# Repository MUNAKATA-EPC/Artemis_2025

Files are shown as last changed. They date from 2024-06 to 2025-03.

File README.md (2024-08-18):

# Artemis_2025

宗高アルテミス 2025シーズンリポジトリです。

2025シーズンはSoccer OpenLeagueに出場します。

## リポジトリについて (引用：2024シーズンリポジトリ)
・フォルダ階層をきれいにしよう  
・パス設定は相対パス基準にしよう  
・あとは動けばなんでもよし。  

## 命名規則など (一部引用：2024シーズンリポジトリ)
・各ロボットごとにプロジェクトファイルを作成しましょう。(英字表記推奨、フォルダ名に2バイト文字は嫌じゃ！！！！)  
　ex. Project_hogehugaNode

・PlatformIO等で作成されたプロジェクトフォルダの名前は (プロジェクト名)-(開発環境) にしましょう。  
　ex. hogehoge-teensy40 hugahuga-seeeduinoxiaorp2040
 
・KiCad、Fusion360などで作成されたフォルダ、ファイルの名前は一目でわかる名前にしましょう。  
　間違ってもファイル名を"unko"とかにするなよ！！！！！(戒め)

 ## 開発環境
 |種類|使用ソフト|
 |:---:|:---|
 |機体設計|Autodesk Fusion|
 |回路設計|KiCad 7.x (only use 7.x ver.)|
 |ソフト開発|Microsoft Visual Studio Code (with PlatformIO)<br>Arduino IDE<br>OpenMV IDE|

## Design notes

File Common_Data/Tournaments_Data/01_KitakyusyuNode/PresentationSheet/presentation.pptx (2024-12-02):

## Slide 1

チーム情報

チームメンバー
松田 魁琉 　 / 　目野 優輝
石原 廉太郎 　/ 　熊抱 崚太

所属ノード
九州ブロック 福岡ノード

参加リーグ
サッカー・オープンリーグ

使用ツール

> Autodesk Fusion
ロボット全体の設計や、3Dプリンターで
印刷・CNCで加工するためのデータ作成
> KiCad 7.0
外注するための基板データの作成
> Visual Studio Code
メインマイコン・各センサー処理用の
マイコンのプログラムの作成
> MaixPy IDE
UnitV(カメラ)に書き込むプログラムの
作成、カラートラッキング用データの
調整

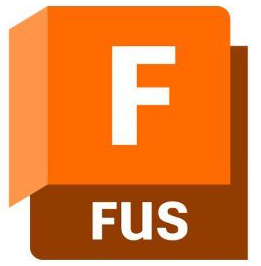
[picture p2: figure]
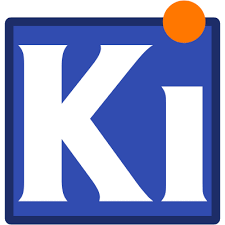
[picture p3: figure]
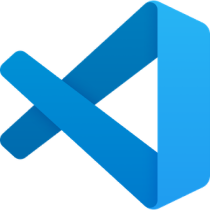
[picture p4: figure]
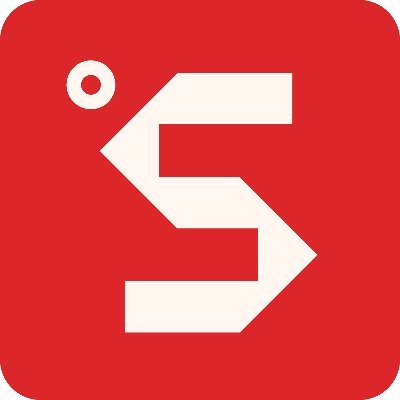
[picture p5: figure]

スポンサー

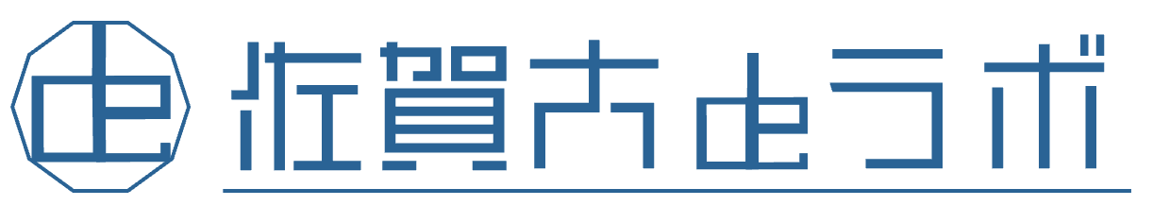
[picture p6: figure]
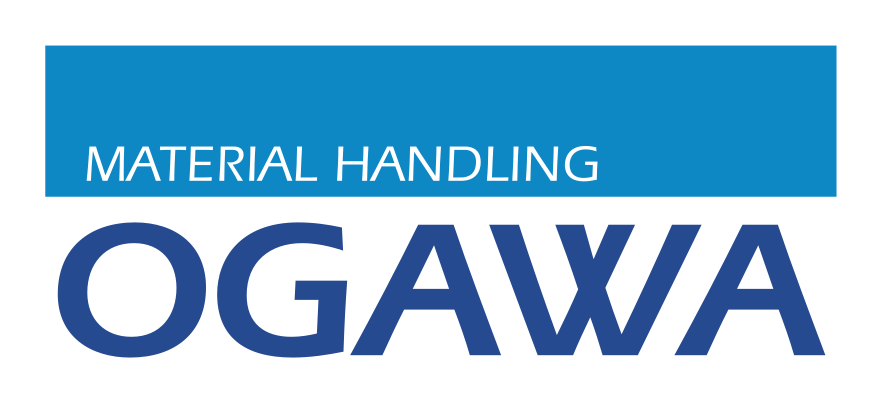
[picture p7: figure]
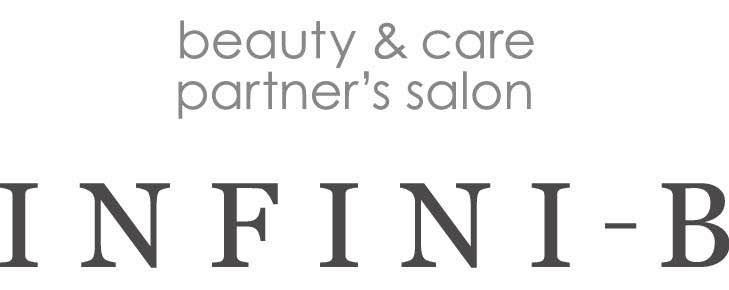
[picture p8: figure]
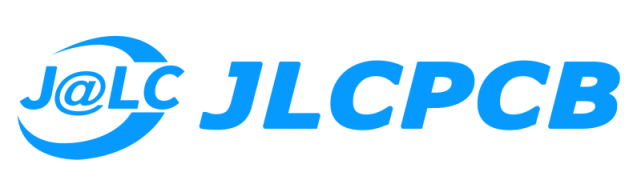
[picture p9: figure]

各種リンク

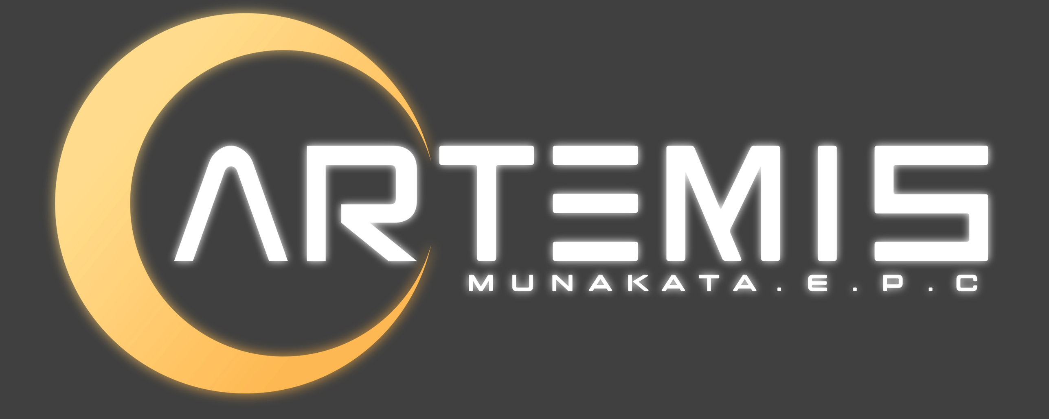
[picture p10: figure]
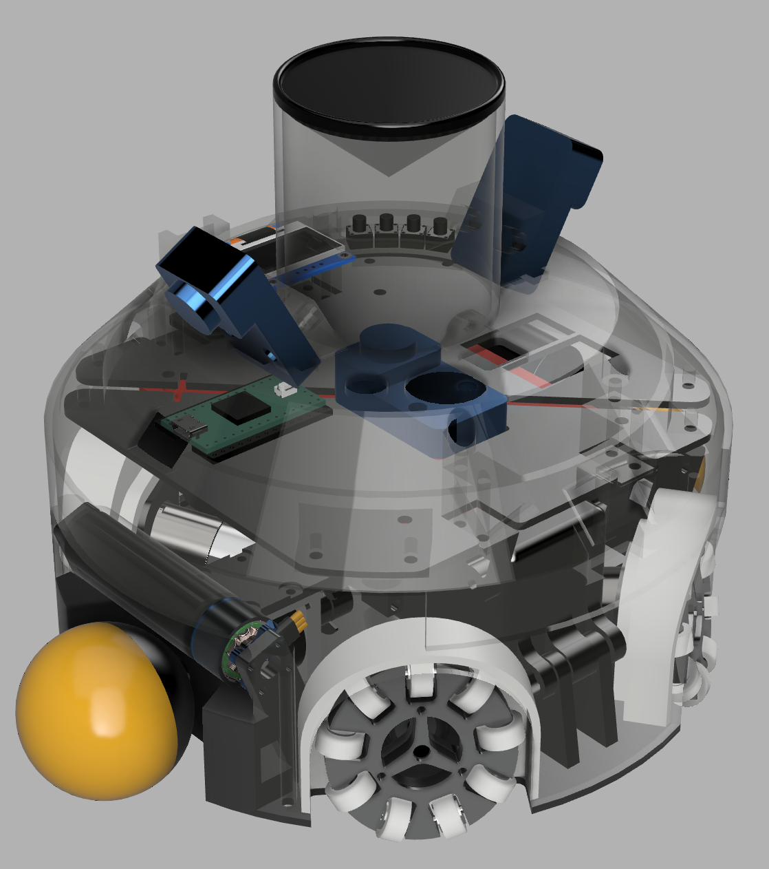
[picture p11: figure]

確実にボールを「見る」

私たちのロボットには、

電源基板 Power Supply Board
【メイン基板方向】
・5V生成
OKL-T/6-W12N-C
【ソレノイド方向】
・48V生成
(昇圧の型番)

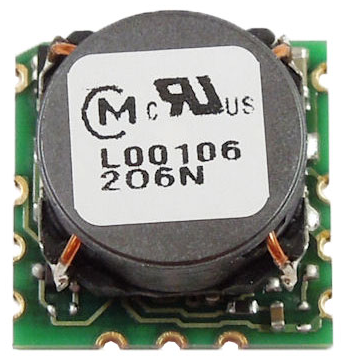
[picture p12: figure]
ムラタ表面実装DC-DCコンバーター OKL-T/6-W12N-C

【ドリブラー部分】
・ESC
??? x 2
・モーター
BLDC x 2

モーター関連
【4輪駆動部分】
・モータードライバ
DSR1202 (DAISEN製)
・モーター
IG22 1:19 x 4

Motors

バッテリー
11.1V 2200mAh

POWER

メイン基板 Main Board

メインマイコン
Teensy 4.0

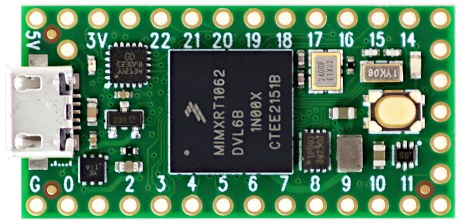
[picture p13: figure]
Teensy® 4.0

ジャイロセンサ
BNO055

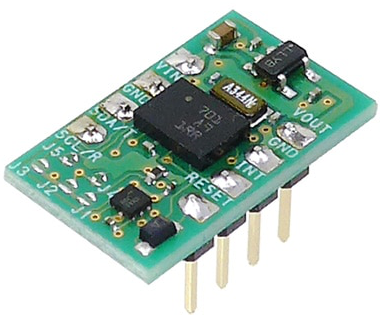
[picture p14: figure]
BNO055使用 9軸センサーフュージョンモジュールキット

UART

I²C

カメラ
UnitV
AI Camera
x 3

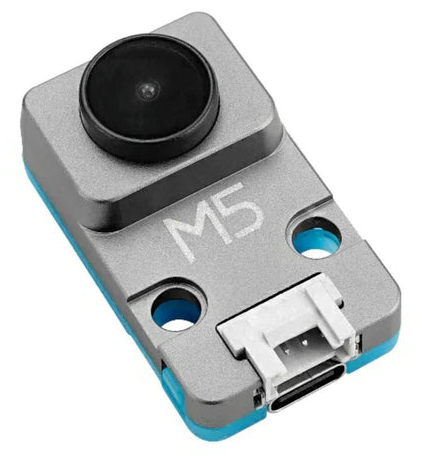
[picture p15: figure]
M5STACK-U078-V-M12

O-LEDディスプレイ
SSD1306

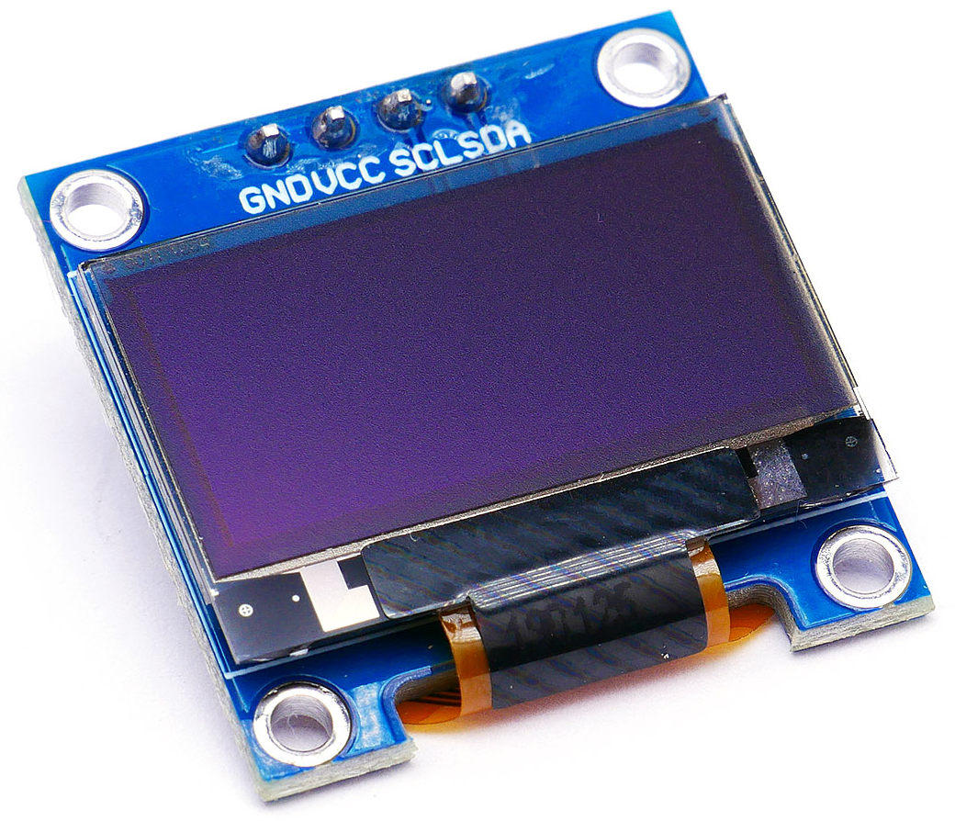
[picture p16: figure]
ESP8255でSSD1306を駆動

I²C

ラインセンサ Line Sensors

マイコン
Seeeduino Xiao x 1
(マルチプレクサを用いて
計16個分のセンサーの値を取得)
センサー
フォトトランジスタ
NJL7502L * 32
(センサーを2つずつ並列に接続)

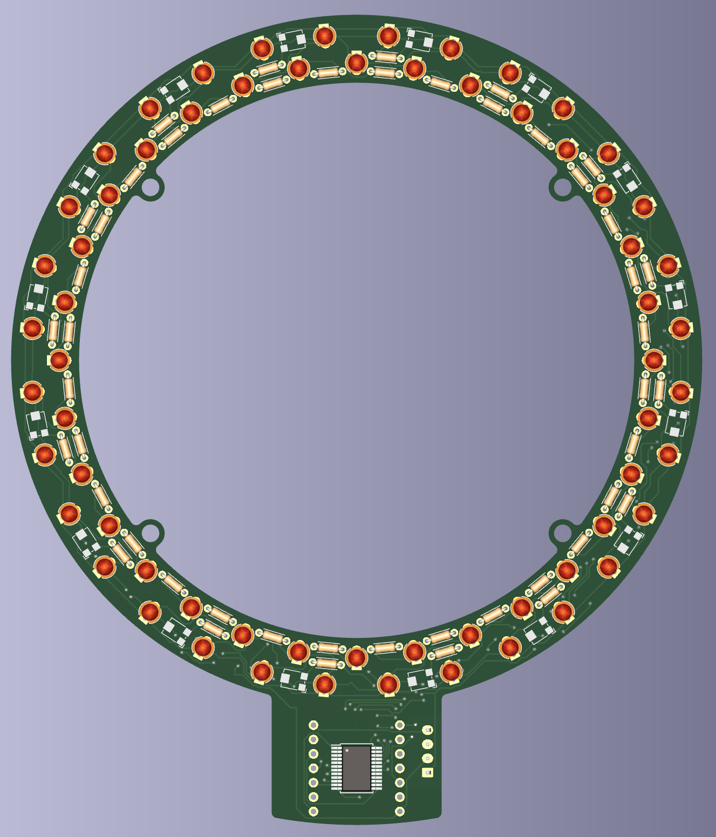
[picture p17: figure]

POWER:5V

UART

POWER:48V

ソレノイド
CB1029 x 2

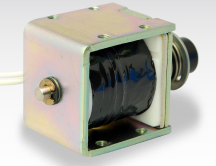
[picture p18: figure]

POWER:12V

UART

・重量 : 100000kg

UIでデータを「可視化」

私たちのロボットには、「ロボットの動作モードのシーム
レスな切替」・「ロボットが持つデータの可視化」を目的として、O-LEDディスプレイと複数のタクトスイッチを搭載しています。これらを活用することで、パソコンを用いずとも
以下に示すようなことができるようになりました。
・アタッカー・ディフェンスモードの瞬間的な切替
・センサーの値の表示や感度の調整
・キッカーやドリブラーなどの機構の動作確認

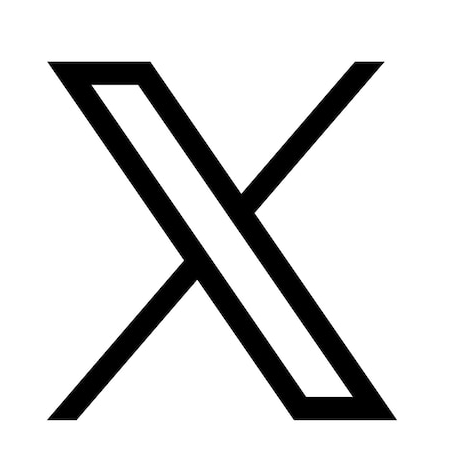
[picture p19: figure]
Twitterのロゴ X のベクトルとイラストを無料でダウンロード | Freepik
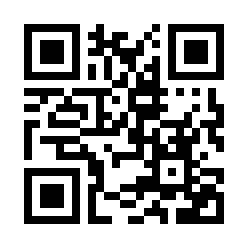
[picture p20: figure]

Artemis Homepage

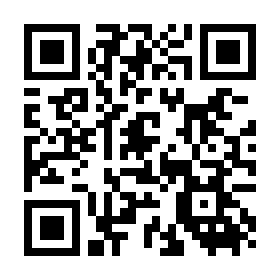
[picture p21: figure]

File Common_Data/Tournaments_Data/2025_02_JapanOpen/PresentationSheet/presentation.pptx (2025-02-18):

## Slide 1

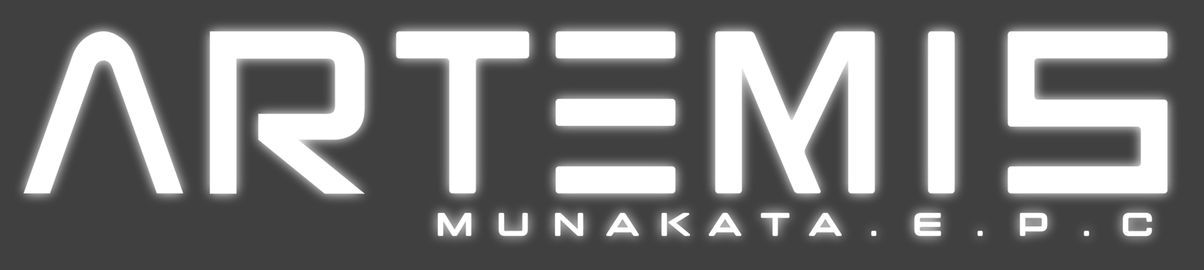
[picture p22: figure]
テキスト, ロゴ AI によって生成されたコンテンツは間違っている可能性があります。

福岡県立宗像高等学校

チームメンバー
松田 魁琉 / 目野 優輝 / 石原 廉太郎 / 熊抱 崚太

チーム概要 – Munako Artemis

私たちは2024シーズンにライトウェイトリーグで世界大会に出場し、世界大会で活躍するオープンリーグのロボットを生で
見てきました。その経験から、オープンリーグにおいてロボットが「圧倒的」であるために必要な要素を考え、今シーズンの
ロボットに反映させました。例えば、電源基板の改良や6方向
カメラの搭載、前後のドリブラー・キッカー搭載などです。
また、現ルールではプッシングを利用したゴール前での
キーパーがとても強いため、どのような守備の方法が良いのか、2種類の方法で研究を行いました。

ロボットの概要 – robot’s overview

所属
九州ブロック 福岡ノード

ロボットの特徴 – robot’s features

圧倒的な安全性の電源基板

従来の電源回路はバッテリーの保護回路と電源スイッチのみが搭載
されたシンプルもので、マイコンによる電圧監視を行っていなかった
ため、目視による電圧監視を怠った場合、バッテリー事故が起こりかねない状態でした。
そこで今回、私たちはマイコンが内蔵されたより安全性、信頼性の
高い電源回路を開発しました。大きな特徴として、FETスイッチと
物理スイッチを用いた2段階スイッチ機能を搭載しています。また、UIやブザーを用いて感覚的に電圧低下を認識することもできます。

さらに、開発するツールにもこだわっています。 GitHubを用いてチーム内で最新の情報を共有するほか、Twitterなどを用いて
過去の私たちの技術を公開しています。また、Visual Studio Codeなどの統合開発環境を用いて効率的に開発を行っています。

ハードウェア

圧倒的な安定性のビジョンシステム

私たちのロボットには、UnitV Ai Cameraを6個搭載しています。
以前は全方位ミラーを用いて1つのカメラで全方向を監視していましたが、
ゴルフボールという小さい物体をどの距離からでも認識できるようにするのは大変でした(図1)。また、ロボット自身がカメラに映りこむことで、至近距離にあるボールがロボットに隠れて認識できないという問題もありました。
これらの問題を解決するため、カメラを6個搭載することで、全方位ミラーの「全方向が見える」という要件を担保しつつ、遠距離の視野の確保や至近距離でのボールの認識を容易に行うことができるようになりました。

ハードウェア

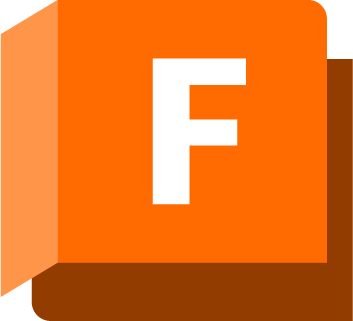
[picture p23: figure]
Fusion 360 CAM | Fusion 360の購入 Autodesk Japan公式法人販売パートナー

Autodesk Fusion
ロボット設計

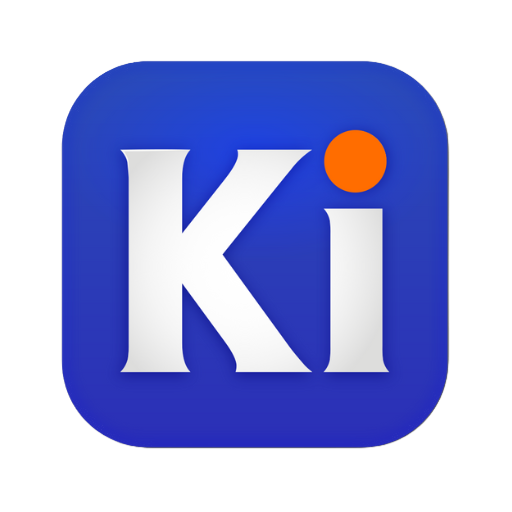
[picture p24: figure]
アイコン AI によって生成されたコンテンツは間違っている可能性があります。

KiCad
回路設計

Visual Studio Code
プログラムの作成

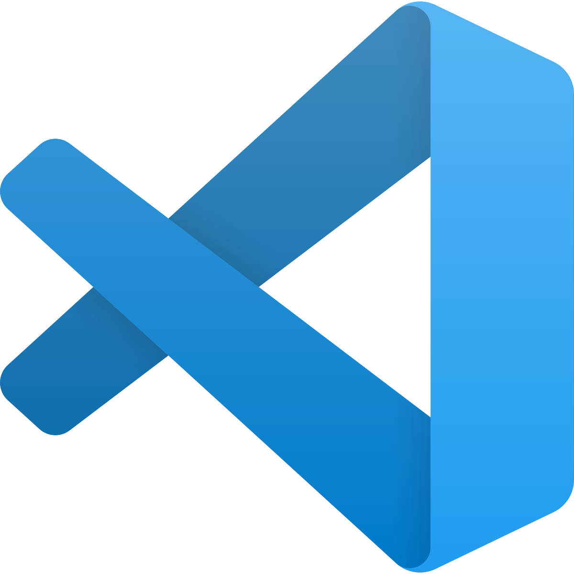
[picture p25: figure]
Visual Studio Code Web版のプレビューが公開 | Qreat

メイン基板との接続
SPI

MaixPy IDE
カメラプログラム
作成

GitHub - sipeed/MaixPy: Easily create AI projects with Python on edge device

GitHub
データ共有

The only platform that shows the full impact of GitHub Copilot

①メイン基板

②UIモジュール基板

鏡, 眺め, 座る, 車 が含まれている画像 AI によって生成されたコンテンツは間違っている可能性があります。

メインマイコン : Teensy 4.0 / ToF処理用マイコン : RP2040

メインマイコンには昨年度から引き続きTeensy4.0を採用しています。マイコンの値段に対して、シリアルの数が多く、処理速度が高いことからコストパフォーマンスが高いことから採用しています。
メインマイコンでは、カメラ・ラインセンサ・電源基板・無線モジュールからの情報を受け取り、モータードライバ・UIモジュールにデータを出力しています。アタッカー・ディフェンダーのプログラムが2台共に搭載されているため、プログラムを書き込むことなく2つの役割を切り替えすることができます。
また、赤外線で距離を計測することができるToFを16個搭載しています。周囲の物体の距離を計測し、距離が近いところはロボットがいると判断し、その部分を避けてボールを運搬することができます。

ディスプレイ : MSP2807 / フルカラーLED : WS2812B-2020 x64

ディスプレイには、メインマイコンが保持しているセンサーの値の表示やモード切替を行うために、フルカラータッチディスプレイであるMSP2807を搭載しており、ロボットをパソコンに接続することなくセンサーの値を確認することができます。
また、基板端に円形にフルカラーLED
であるWS2812B-2020を搭載しており、
ボールやゴールの角度、ラインセンサー
の反応位置などをより視覚的に認識する
ことができます。
この基板を搭載することで、ロボットの
デバッグ性が飛躍的に向上しました。

モジュール写真

センサ : UnitV Ai Camera x32
マイコン : RP2040

サッカー競技において、白線の外に出てしまうことは試合に参加できる時間が短くなることであるため、非常に不利な状況となります。そのため、白線を正確に素早く認識するために非常に多くのセンサを円形に搭載しています。円形に搭載することで、複数のセンサーが反応した際に、各センサーの角度をベクトル合成し、
「白線の外に出ない」
角度を簡単に算出する
ことができます。
また、キーパーでは
反応しているセンサー
の角度を用いることで、
ゴール前の白線上で
ライントレースを
しながらゴールを守る
ことができます。

前後ドリブラー・キッカー搭載で圧倒的な得点率を

私たちのロボットは、ドリブラー・キッカーを前後に搭載しており、この2つを有効活用して試合を有利に進めていきます。

図3 全方位ミラーによるカメラの視界

ソフトウェア

どちらもゴルフボールをオレンジの丸で示している。

図4 6方向カメラによるカメラの視界

③カメラユニット

カメラ : UnitV Ai Camera x6

ゴルフボールを色認識するために、比較的
低価格で入手性が高く、安定した使用感を
得られるUnitVを採用しました。6個のカメラのデータをTeensy 4.0で取得し、ボールおよびゴールの角度・距離を計算してメイン基板に出力しています。
(詳しい情報は「ロボットの特徴」を参照。)

メイン基板との接続
UART

⑤ラインセンサ

前方にあるドリブラー・キッカーは、
「ゴール方向に素早く正確にシュートする」
役割を担います。ドリブラーでボールを
補足した後、相手ゴールまで近づき、
キッカーを用いて空いているゴールの方向
へとシュートを放ちます(図4右側)。
また、ドリブラーを用いることで、
ゴールの横にあり、そのままではゴールに
入れることができないボール(図4左の
赤領域)も保持したまま後ろに運ぶことで、
ゴールに向かってシュートを放つこと
が可能になります(図4左の青領域)。

最強のキーパーを作るために

導入
サッカー競技において、シュートを防いだり、プッシングを発生させてボールを相手の中立点に移動させることができる「キーパー」の役割は非常に重要であり、試合の勝敗を左右する存在だと考えました。そこで、どのような守備方法がゴールを守備しやすいのか研究することにしました。
研究内容
方法1「白線上でボールに対して真正面から守備する(図7)」、方法2「ゴールの中心・ロボット・ボールが一直線になる白線上の点で守備する(図8)」のどちらがゴールを守備できるのか調べる。
研究方法
①方法1でロボットを動かし、次の
「手順」に沿って実験を行う。
②方法2でロボットを動かし、次の
「手順」に沿って実験を行う。
③2つの実験結果から、どちらの方が
守備しやすいのか考察する。
「手順」右上図のようにボールの位置(中立点)・角度を変化させ、
10回試行し、シュートを防いだ回数を記録する。

ボール

ロボット

図7 方法1における守備の簡略図

図8 方法2における守備の簡略図

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
図5 前ドリブラー・キッカーに
よるロボットの動作

ソフトウェア

後方にあるドリブラー・キッカーは、
「ボールを隠して運び、相手に見せずに
シュートする」役割を担います。
ロボットの後方に存在しているボールは
回り込むことなく直接ドリブラーで
捕捉し、後ろに隠したままゴールまで
運びます。ロボットがゴールより外側に
いる場合、壁側から回転をしてボールを
キックします(図6右側)。また、ロボットの
真後ろにキーパーがいる場合、ボールに
回転をかけてカーブシュートをし(図6左側)
相手に邪魔されずシュートを行います。

研究結果
研究結果は上の表のようになった。

| ① | ② | ③ | ④ | ⑤ | ⑥ | ⑦ | ⑧
方法① | N回 | N回 | N回 | N回 | N回 | N回 | N回 | N回
方法② | N回 | N回 | N回 | N回 | N回 | N回 | N回 | N回

敵

キック

図6 後ろドリブラー・キッカー
によるロボットの動き


②

①

③

⑦

④

⑤

⑥

メイン基板との接続
UART

④統合電源基板

今シーズンの私たちのロボットのコンセプトである「圧倒的」に則り、圧倒的な安全性を持った電源基板を作成しました。
バッテリーには3セル(11.1V)で容量の大きなKypom 2200mAh 3Cellを採用し、電源基板自体にマイコン(RP2040)およびブザーを搭載することで、電圧低下の対策をしています。
(詳しい情報は「ロボットの特徴」を参照)

⑥キッカー・ドリブラーモジュール

ソレノイド : CB1029 (タカハ機工) x2
BLDC : Mini 1525 3500KV x2

私たちのロボットには前後にドリブラーとキッカーを搭載しています。ボールをキックするキッカーについて、オープンリーグではロボットの直径が18cmという制限が存在しているので、ライトウェイトで使用していた
ソレノイド(CB1037)より1回り小さいCB1029を採用しています。キッカーの回路では、PchMOSFETとNchMOSFETを利用してコンデンサの充電部分とソレノイドの駆動部分を分離し、ノイズを低減しています。
また、ボールを運搬するためのドリブラー
にはBLDCを採用することで、DCモーター
よりもドリブラー部分を小型化することが
できました。
ロボットのメンテナンス性を向上させる
ために、ロボット下部のネジ4個を外すだけ
でこのユニットにアクセスすることが
できるように設計しました。

各基板に
12Vを供給

モジュール写真

研究

ボールを
運搬・キック

⑦モータードライバモジュール

モーター : IG22 19:1 x4
モータードライバ : TB67H450FNG x4

モーターにはIG22 19:1を採用しています。現在は在庫がなく高価なものとなっていますが、以前は入手性が高く低価格であり、自チームの在庫が多かったため採用しています。また、モータードライバにはTB67H450FNGを採用しています。オープンリーグのロボットは部品を直径18cmに収めないといけない都合上、基板サイズも小さく
なければならないことから、部品サイズが小さく、流すことのできる電流が大きいこのドライバを採用
しました。
また、ドリブラーに用いている
BLDCの制御(ESCを使用)も管理して
おり、駆動系をこのモジュール1つで
管理できるようになっているため、
ロボットのメンテナンス性も向上
するような設計となっています。

モーターを
回転・停止

メイン基板との接続
UART

情報共有が生む、より強いチームワーク

RCJに参加する上で、技術の共有を
することは必要不可欠だと考えています。
私たちは、SNSやチームのブログを
通して、様々な技術や情報を身に
付けると同時に、私たちが学んだ技術
や発見したことの発信も行っています。
右のQRコードより、チームのX
アカウント・ブログにアクセスする
ことができます。ぜひご覧ください。

チーム活動


チームブログ

ユニット
写真

ユニット
写真


Xアカウント
(@munako_artemis)

SWO???

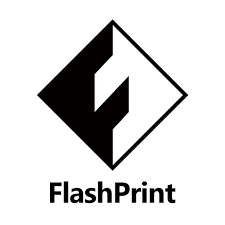
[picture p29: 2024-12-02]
Common_Data/Tournaments_Data/2025_02_JapanOpen/PresentationSheet/pictures/images__.png

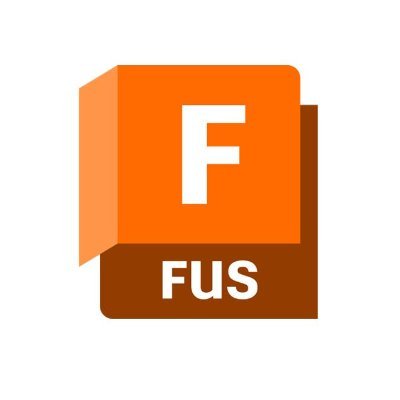
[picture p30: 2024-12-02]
Common_Data/Tournaments_Data/2025_02_JapanOpen/PresentationSheet/pictures/sVyP1AdT_400x400.jpg

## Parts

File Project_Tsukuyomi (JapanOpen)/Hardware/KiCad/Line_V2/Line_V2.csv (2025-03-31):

Comment | Designator | Footprint | LCSC
CD74HC4067SM | U1 | Package_SO:SSOP-24_5.3x8.2mm_P0.65mm | C98457

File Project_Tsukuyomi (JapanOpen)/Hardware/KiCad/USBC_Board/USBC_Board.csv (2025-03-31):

Comment | Designator | Footprint | LCSC
Conn_01x01_Socket | J1,J2,J3,J4,J5,J6,J7,J8,J9,J10,J12,J13,J14,J15,J16,J17,J18,J19,J20,J21,J22 | TestPoint:TestPoint_Pad_D1.0mm
DX07P024MJ1R1500 | J11 | DX07P024MJ1R1500:JAE_DX07P024MJ1R1500 | C134112

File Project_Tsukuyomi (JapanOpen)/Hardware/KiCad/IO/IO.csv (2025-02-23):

Comment | Designator | Footprint | LCSC
C | C1,C3 | Capacitor_SMD:C_1210_3225Metric_Pad1.33x2.70mm_HandSolder
C | C2,C4 | Capacitor_THT:C_Disc_D3.0mm_W1.6mm_P2.50mm
WS2812B | D1,D2,D3,D4,D5,D6,D7,D8,D9,D10,D11,D12,D13,D14,D15,D16,D17,D18,D19,D20,D21,D22,D23,D24,D25,D26,D27,D28,D29,D30,D31,D32,D33,D34,D35,D36,D37,D38,D39,D40,D41,D42,D43,D44,D45,D46,D47,D48,D49,D50,D51,D52,D53,D54,D55,D56,D57,D58,D59,D60,D61,D62,D63,D64 | LED_SMD:LED_WS2812B-2020_PLCC4_2.0x2.0mm
Conn_01x14_Socket | J1 | Connector_PinHeader_2.54mm:PinHeader_1x14_P2.54mm_Vertical
Conn_01x04_Socket | J2 | Connector_JST:JST_XH_B4B-XH-A_1x04_P2.50mm_Vertical
Conn_01x04_Socket | J3 | Connector_PinHeader_2.54mm:PinHeader_1x04_P2.54mm_Vertical
UJ32-C-V-G-TH-5-P24-TR | J4 | Connector_USB:USB_C_Receptacle_GCT_USB4115-03-C
Conn_01x07_Socket | J5 | Connector_PinHeader_2.54mm:PinHeader_1x07_P2.54mm_Vertical
AZ1084-3.3 | U1 | Package_TO_SOT_SMD:TO-252-2
AZ1084-5.0 | U2 | Package_TO_SOT_SMD:TO-252-2
TWE-L-WX | U3 | RF_Module:MonoWireless_TWE-L-WX

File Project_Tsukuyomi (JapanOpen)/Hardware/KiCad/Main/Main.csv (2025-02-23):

Comment | Designator | Footprint | LCSC
Buzzer | BZ1 | Buzzer_Beeper:Buzzer_Murata_PKLCS1212E
C_Small | C1,C2 | Capacitor_SMD:C_0402_1005Metric | C1557
C | C3,C4 | Capacitor_SMD:C_1210_3225Metric_Pad1.33x2.70mm_HandSolder
C | C5,C6,C7,C8,C9,C10,C11,C12 | Capacitor_SMD:C_0402_1005Metric | C1525
WS2812B | D1 | LED_SMD:LED_WS2812B_PLCC4_5.0x5.0mm_P3.2mm
USB_C_Receptacle_USB2.0 | J1,J20 | Connector_USB:USB_C_Receptacle_GCT_USB4105-xx-A_16P_TopMnt_Horizontal | C136423
UJ32-C-V-G-TH-5-P24-TR | J14,J19 | Connector_USB:USB_C_Receptacle_GCT_USB4115-03-C | C5342428
Conn_01x06_Socket | J2,J3,J4,J5,J6,J7,J8,J9,J10,J11,J12,J13,J15,J16,J17,J18 | Connector_PinHeader_2.54mm:PinHeader_1x06_P2.54mm_Horizontal
Conn_01x04_Socket | J21 | Connector_JST:JST_XH_B4B-XH-A_1x04_P2.50mm_Vertical
Conn_01x06_Socket | J22,J23 | Connector_JST:JST_XH_B6B-XH-A_1x06_P2.50mm_Vertical
1k | R1,R2 | Resistor_SMD:R_0402_1005Metric | C11702
5.1k | R3,R4,R7,R8,R9,R10,R13,R14 | Resistor_SMD:R_0402_1005Metric | C25905
27 | R5,R6,R11,R12 | Resistor_SMD:R_0402_1005Metric | C25100
SW_Push | SW1,SW2 | Button_Switch_THT:SW_Tactile_SPST_Angled_PTS645Vx31-2LFS
SW_Push | SW3 | Button_Switch_THT:SW_PUSH_6mm
W25Q128JVS | U1 | Package_SO:SOIC-8_5.23x5.23mm_P1.27mm | C97521
RP2040 | U2 | Package_DFN_QFN:QFN-56-1EP_7x7mm_P0.4mm_EP3.2x3.2mm | C2040
AZ1084-5.0 | U3 | Package_TO_SOT_SMD:TO-252-2
AZ1084-3.3 | U4 | Package_TO_SOT_SMD:TO-252-2
Teensy4.0 | U5 | Teensy_Breakout:Teensy_Brakeout
AE-BNO055-BO | U6 | Package_DIP:CERDIP-8_W7.62mm_SideBrazed
Crystal_GND24 | Y1 | Crystal:Crystal_SMD_2520-4Pin_2.5x2.0mm | C7294610

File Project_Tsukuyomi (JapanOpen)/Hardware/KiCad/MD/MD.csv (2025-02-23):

Comment | Designator | Footprint | LCSC
C_Small | C1,C2 | Capacitor_SMD:C_0402_1005Metric | C1557
0.1μ | C3,C4,C5,C6,C7,C8,C9,C10,C11 | Capacitor_SMD:C_0402_1005Metric | C1525
LED | D1,D2,D3,D4,D5 | LED_SMD:LED_0603_1608Metric_Pad1.05x0.95mm_HandSolder
USB_C_Receptacle_USB2.0 | J1 | Connector_USB:USB_C_Receptacle_G-Switch_GT-USB-7010ASV | C136423
Conn_01x08_Socket | J2,J3 | Connector_PinHeader_2.54mm:PinHeader_1x08_P2.54mm_Vertical
Conn_01x02_Socket | J4,J5,J6,J7 | Connector_JST:JST_XH_B2B-XH-A_1x02_P2.50mm_Vertical
5.1k | R1,R2 | Resistor_SMD:R_0402_1005Metric | C25905
80 | R10,R11 | Resistor_SMD:R_0402_1005Metric
27 | R3,R4 | Resistor_SMD:R_0402_1005Metric | C25100
1k | R5,R6,R7,R8 | Resistor_SMD:R_0402_1005Metric | C11702
100 | R9 | Resistor_SMD:R_0402_1005Metric | C25076
SW_Push | SW1,SW2 | Button_Switch_SMD:SW_SPST_B3U-1000P
W25Q128JVS | U1 | Package_SO:SOIC-8_5.23x5.23mm_P1.27mm | C97521
RP2040 | U2 | Package_DFN_QFN:QFN-56-1EP_7x7mm_P0.4mm_EP3.2x3.2mm | C2040
TB67H450FNG_EL | U3,U4,U5,U6 | TB67H450FNG_EL:SOIC127P599X175-9N
AZ1084-3.3 | U7 | Package_TO_SOT_SMD:TO-252-2
Crystal_GND24 | Y1 | Crystal:Crystal_SMD_EuroQuartz_MT-4Pin_3.2x2.5mm | C7294610

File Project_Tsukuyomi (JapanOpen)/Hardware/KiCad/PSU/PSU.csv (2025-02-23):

Comment | Designator | Footprint | LCSC
Battery | BT1 | Connector_AMASS:AMASS_XT60-M_1x02_P7.20mm_Vertical
Buzzer | BZ1 | Buzzer_Beeper:Buzzer_Murata_PKLCS1212E
0.1μ | C1,C2,C3,C6,C7,C8,C9,C11 | Capacitor_SMD:C_0402_1005Metric | C1525
47μ | C10 | Capacitor_SMD:C_1210_3225Metric_Pad1.33x2.70mm_HandSolder
C_Small | C4,C5 | Capacitor_SMD:C_0402_1005Metric | C1557
LED | D1,D2,D3,D4,D5 | LED_SMD:LED_0603_1608Metric_Pad1.05x0.95mm_HandSolder
D | D6 | Diode_THT:D_DO-27_P12.70mm_Horizontal
Fuse15A | F1 | Fuse:Fuseholder_Clip-5x20mm_Littelfuse_520_Inline_P20.50x5.80mm_D1.30mm_Horizontal
USB_C_Receptacle_USB2.0 | J1 | Connector_USB:USB_C_Receptacle_GCT_USB4105-xx-A_16P_TopMnt_Horizontal
Conn_01x08_Socket | J2,J3 | Connector_PinSocket_2.54mm:PinSocket_1x08_P2.54mm_Vertical
Conn_01x04_Socket | J4 | Connector_PinHeader_2.54mm:PinHeader_1x04_P2.54mm_Horizontal
Conn_01x02_Socket | J5 | Connector_AMASS:AMASS_XT30PW-F_1x02_P2.50mm_Horizontal
Conn_01x02_Socket | J6 | Connector_PinHeader_2.54mm:PinHeader_1x02_P2.54mm_Vertical
PMOS | Q1 | Package_TO_SOT_SMD:TO-252-2
1k | R1,R2,R3,R4,R9,R15,R16 | Resistor_SMD:R_0402_1005Metric | C11702
5.1k | R10,R11 | Resistor_SMD:R_0402_1005Metric | C25905
27 | R12,R13 | Resistor_SMD:R_0402_1005Metric | C25100
330 | R14 | Resistor_SMD:R_0402_1005Metric | C25104
100 | R5 | Resistor_SMD:R_0402_1005Metric | C25076
80 | R6,R7 | Resistor_SMD:R_0402_1005Metric
3k | R8 | Resistor_SMD:R_0402_1005Metric | C25784
Varistor | RV1,RV2 | Varistor:RV_Disc_D9mm_W3.3mm_P5mm
SW_Push | SW1,SW2 | Button_Switch_SMD:SW_SPST_B3U-1000P
W25Q128JVS | U1 | Package_SO:SOIC-8_5.23x5.23mm_P1.27mm | C97521
RP2040 | U2 | Package_DFN_QFN:QFN-56-1EP_7x7mm_P0.4mm_EP3.2x3.2mm | C2040
SFH617A-1 | U3 | Package_DIP:DIP-4_W7.62mm
AZ1084-5.0 | U4 | Package_TO_SOT_SMD:TO-252-2
Crystal_GND24 | Y1 | Crystal:Crystal_SMD_2016-4Pin_2.0x1.6mm | C7294610

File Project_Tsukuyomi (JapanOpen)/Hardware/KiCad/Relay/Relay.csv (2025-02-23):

Comment | Designator | Footprint | LCSC
UJ32-C-V-G-TH-5-P24-TR | J1 | UJ32-C-V-G-TH-5-P24-TR:SAMESKY_UJ32-C-V-G-TH-5-P24-TR | C5342428
Conn_01x05_Socket | J2 | Connector_JST:JST_XH_S5B-XH-A_1x05_P2.50mm_Horizontal
Conn_01x02_Socket | J3,J4 | Connector_AMASS:AMASS_XT30PW-M_1x02_P2.50mm_Horizontal
Conn_01x03_Socket | J5,J6 | Connector_JST:JST_XH_B3B-XH-A_1x03_P2.50mm_Vertical
Conn_01x04_Socket | J7 | Connector_PinSocket_2.54mm:PinSocket_1x04_P2.54mm_Horizontal
Conn_01x08_Socket | J8 | Connector_PinSocket_2.54mm:PinSocket_2x06_P2.54mm_Horizontal
Conn_01x04_Socket | J9 | Connector_JST:JST_XH_B4B-XH-A_1x04_P2.50mm_Vertical
~ | U1,U2 | ESC:ESC_20A

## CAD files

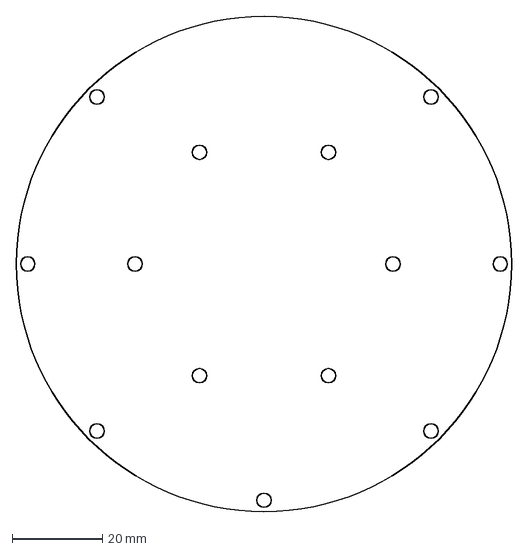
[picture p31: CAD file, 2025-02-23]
Project_Tsukuyomi (JapanOpen)/Hardware/KiCad/Main/Main.dxf
110.0 x 110.0 mm

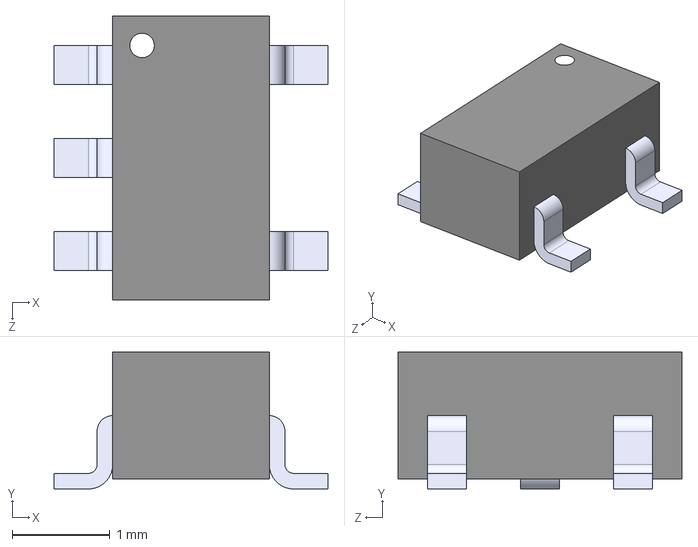
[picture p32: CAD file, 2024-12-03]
Common_Data/component_test/RP2040/KiCad_Data/kibrary/TCR3DF33_LM_CT/TCR3DF33_LM_CT.step
2.80 x 1.40 x 2.90 mm

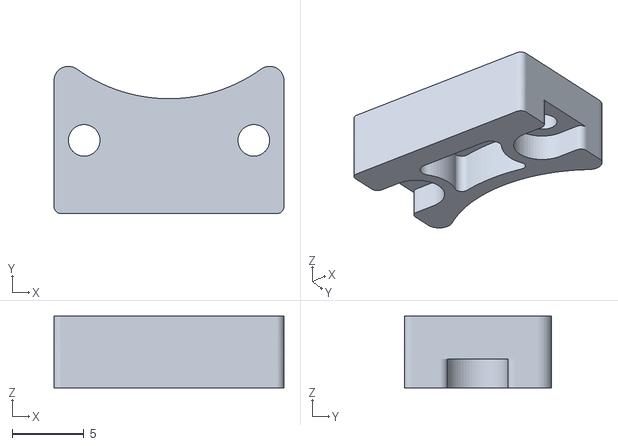
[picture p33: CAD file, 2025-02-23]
Project_Tsukuyomi (JapanOpen)/Hardware/JLCPCB/Printer/motor mount 3-1.stl
16.0 x 10.3 x 5.00

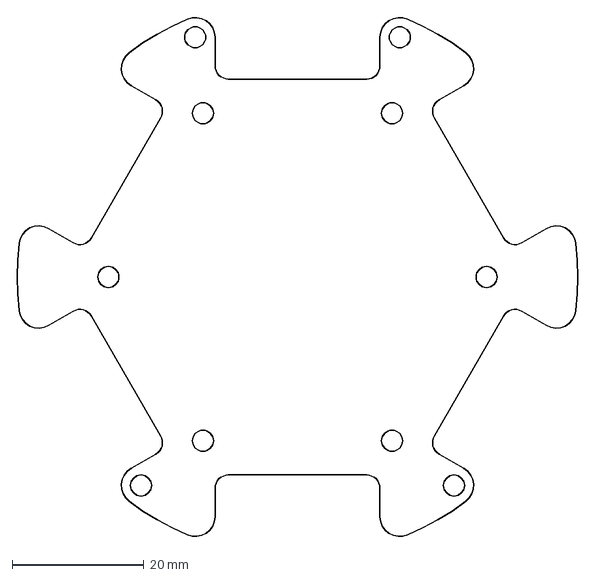
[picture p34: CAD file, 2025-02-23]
Project_Tsukuyomi (JapanOpen)/Hardware/KiCad/CAM/CAM.dxf
85.2 x 79.0 mm

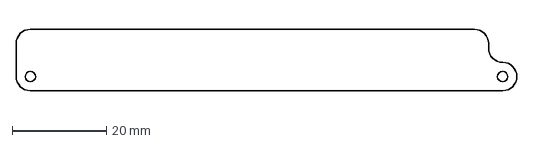
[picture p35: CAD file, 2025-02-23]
Project_Tsukuyomi (JapanOpen)/Hardware/KiCad/Capasitor/Cap.dxf
106.0 x 13.0 mm

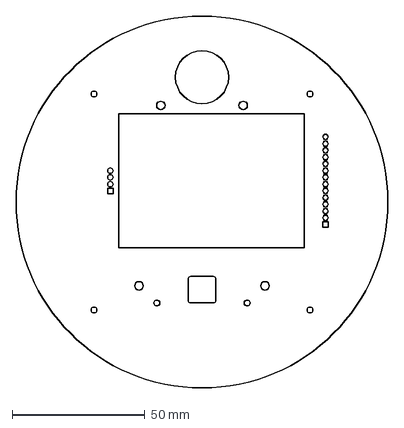
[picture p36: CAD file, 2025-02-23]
Project_Tsukuyomi (JapanOpen)/Hardware/KiCad/IO/IO.dxf
140.0 x 140.0 mm

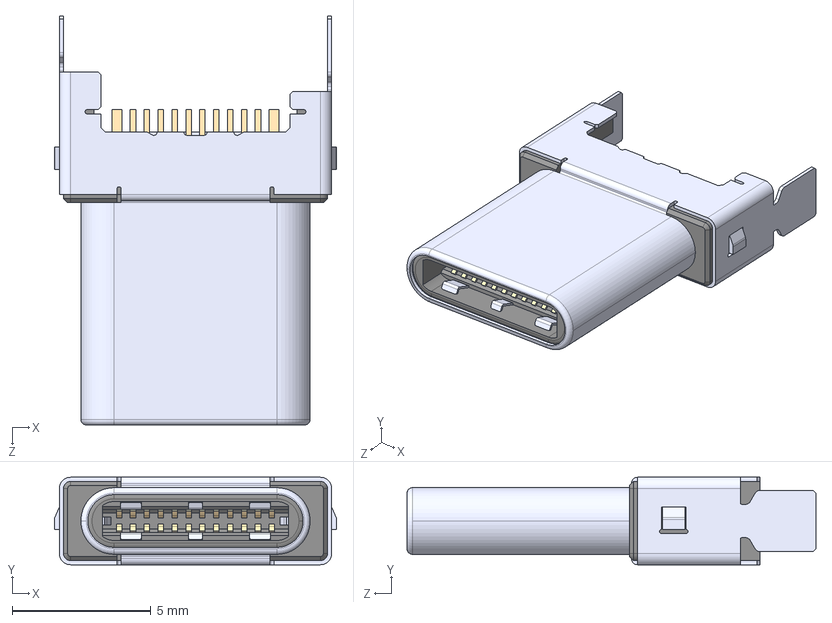
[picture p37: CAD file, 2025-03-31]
Project_Tsukuyomi (JapanOpen)/Hardware/KiCad/KiCad_Library/DX07P024MJ1R1500/DX07P024MJ1R1500.step
10.2 x 3.15 x 14.7 mm

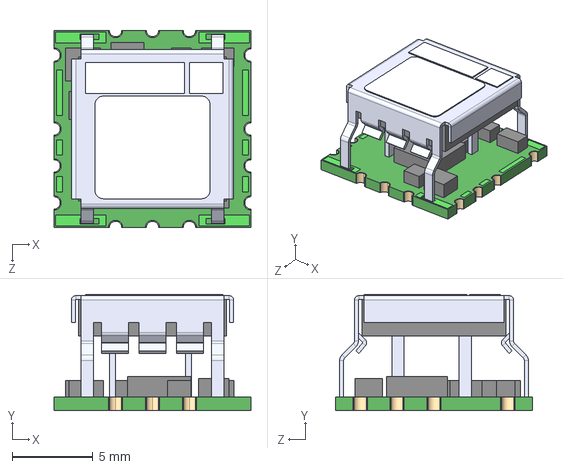
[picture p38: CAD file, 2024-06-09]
Project_Tsukuyomi (JapanOpen)/Hardware/KiCad/KiCad_Library/OKL-T_6-W12N-C/OKL-T_6-W12N-C.step
12.2 x 7.19 x 12.2 mm

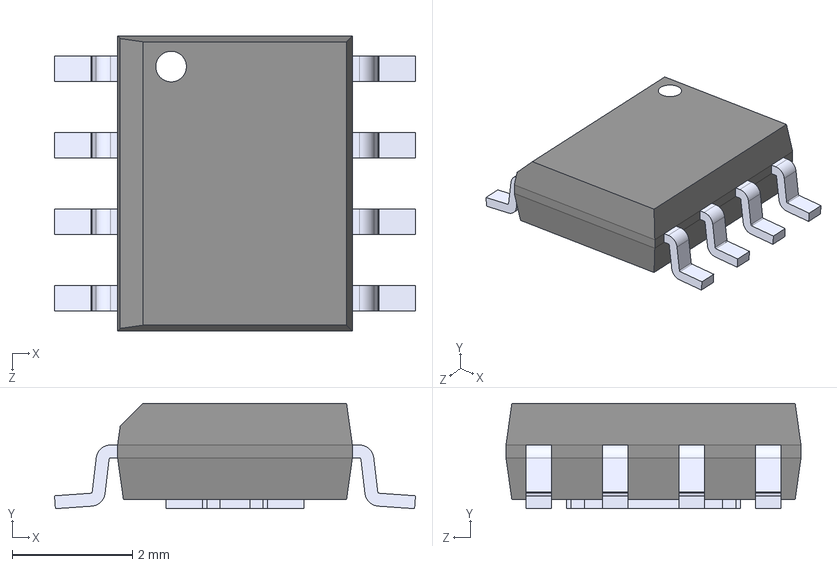
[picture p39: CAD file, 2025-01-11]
Project_Tsukuyomi (JapanOpen)/Hardware/KiCad/KiCad_Library/TB67H450FNG_EL/TB67H450FNG_EL.step
6.00 x 1.75 x 4.90 mm

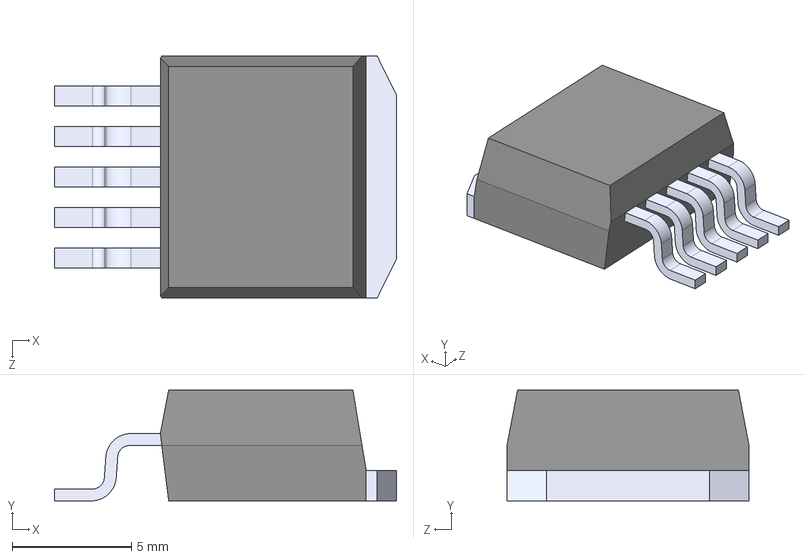
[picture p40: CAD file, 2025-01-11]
Project_Tsukuyomi (JapanOpen)/Hardware/KiCad/KiCad_Library/XL6009/XL6009.step
14.3 x 4.65 x 10.2 mm

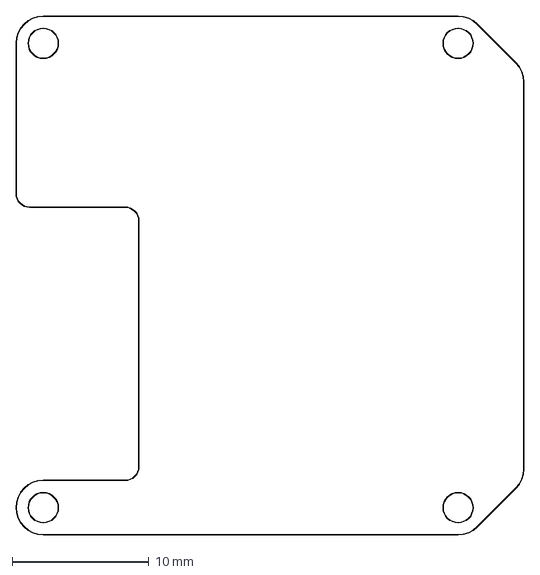
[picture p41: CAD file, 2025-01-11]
Project_Tsukuyomi (JapanOpen)/Hardware/KiCad/MD/MD.dxf
37.2 x 38.0 mm

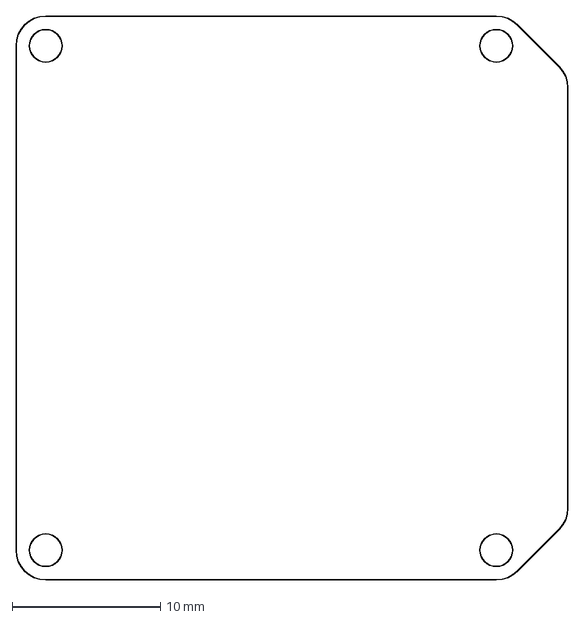
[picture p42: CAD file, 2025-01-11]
Project_Tsukuyomi (JapanOpen)/Hardware/KiCad/PSU/PSU.dxf
37.2 x 38.0 mm

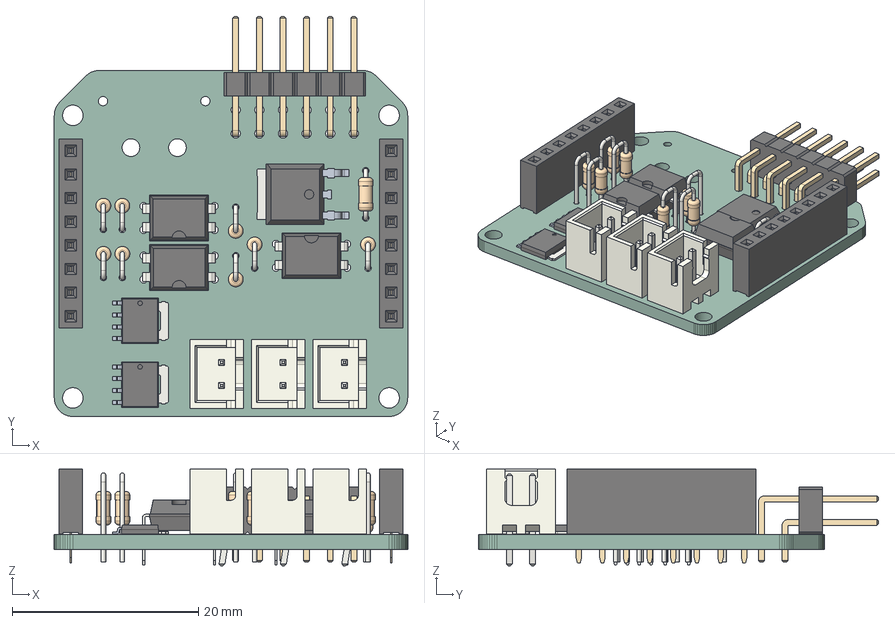
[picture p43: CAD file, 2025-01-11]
Project_Tsukuyomi (JapanOpen)/Hardware/STEP/Kicker.step
38.0 x 43.0 x 10.4 mm
PinSocket_1x08_P254mm_Vertical x 2
R_Axial_DIN0204_L36mm_D16mm_P254mm_Vertical x 8
CQ assembly x 3
JST_B2B_XH_A x 3
DIP-4_W7.62mm x 3
R_Axial_DIN0204_L36mm_D16mm_P508mm_Horizontal
PinHeader_2x06_P254mm_Horizontal
Kicker PCB

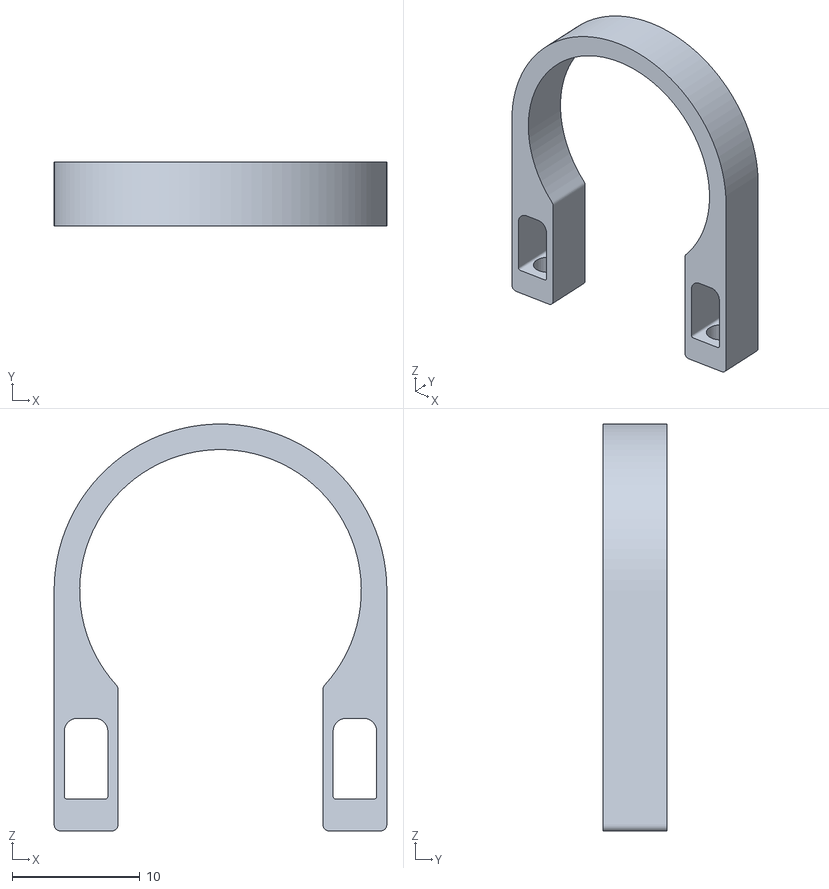
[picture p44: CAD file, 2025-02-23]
Project_Tsukuyomi (JapanOpen)/Hardware/JLCPCB/Printer/motor mount 1-1.stl
26.0 x 5.00 x 31.8

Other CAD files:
Project_Tsukuyomi (JapanOpen)/Hardware/STEP/VoltageBooster.step
Project_Tsukuyomi (JapanOpen)/Hardware/JLCPCB/Printer/rim.stl
Project_Tsukuyomi (JapanOpen)/Hardware/JLCPCB/Printer/motormount2-1.stl
Project_Tsukuyomi (JapanOpen)/Hardware/JLCPCB/Printer/handle.stl
Project_Tsukuyomi (JapanOpen)/Hardware/KiCad/Line/Line.dxf

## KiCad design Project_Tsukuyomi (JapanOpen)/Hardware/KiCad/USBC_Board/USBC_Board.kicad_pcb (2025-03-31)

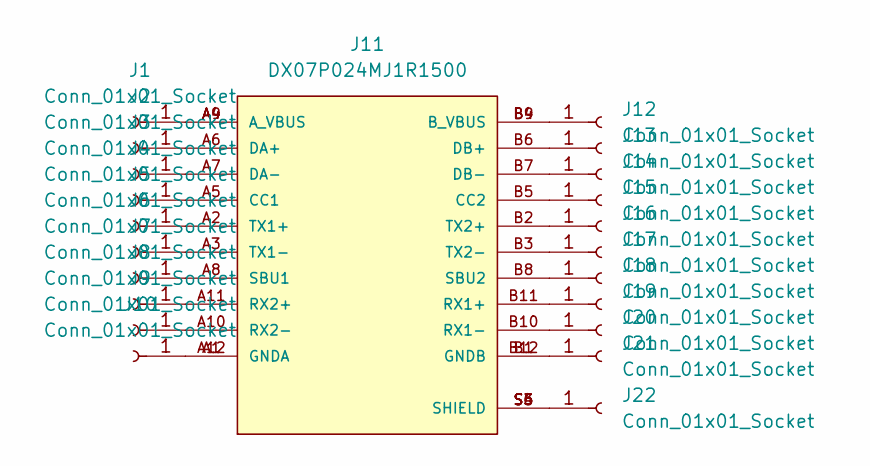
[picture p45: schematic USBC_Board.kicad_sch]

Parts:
J1, J2, J3, J4, J5, J6, J7, J8, J9, J10, J12, J13, J14, J15, J16, J17, J18, J19, J20, J21, J22: Conn_01x01_Socket; TestPoint_Pad_D1.0mm
J11: DX07P024MJ1R1500; JAE_DX07P024MJ1R1500; PARTREV 1.0; LCSC C134112

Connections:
unnamed: J1.1, J11.A4 (A_VBUS), J11.A9 (A_VBUS)
unnamed: J10.1, J11.A1 (GNDA), J11.A12 (GNDA)
unnamed: J4.1, J11.A5 (CC1)
unnamed: J11.B5 (CC2), J15.1
unnamed: J2.1, J11.A6 (DA+)
unnamed: J3.1, J11.A7 (DA-)
unnamed: J11.B6 (DB+), J13.1
unnamed: J11.B7 (DB-), J14.1
unnamed: J11.B11 (RX1+), J19.1
unnamed: J11.B10 (RX1-), J20.1
unnamed: J8.1, J11.A11 (RX2+)
unnamed: J9.1, J11.A10 (RX2-)
unnamed: J7.1, J11.A8 (SBU1)
unnamed: J11.B8 (SBU2), J18.1
unnamed: J5.1, J11.A2 (TX1+)
unnamed: J6.1, J11.A3 (TX1-)
unnamed: J11.B2 (TX2+), J16.1
unnamed: J11.B3 (TX2-), J17.1
unnamed: J11.B4 (B_VBUS), J11.B9 (B_VBUS), J12.1
unnamed: J11.B1 (GNDB), J11.B12 (GNDB), J21.1
unnamed: J11.S3 (SHIELD), J11.S4 (SHIELD), J11.S5 (SHIELD), J11.S6 (SHIELD), J22.1

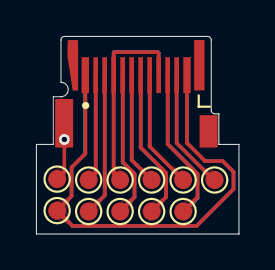
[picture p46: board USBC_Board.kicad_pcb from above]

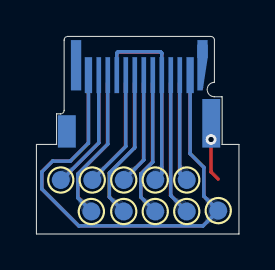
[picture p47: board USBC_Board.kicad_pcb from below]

Board: 2 copper layers, 11.2 x 11.0 mm, 22 parts (10 on the bottom side), 21 nets.

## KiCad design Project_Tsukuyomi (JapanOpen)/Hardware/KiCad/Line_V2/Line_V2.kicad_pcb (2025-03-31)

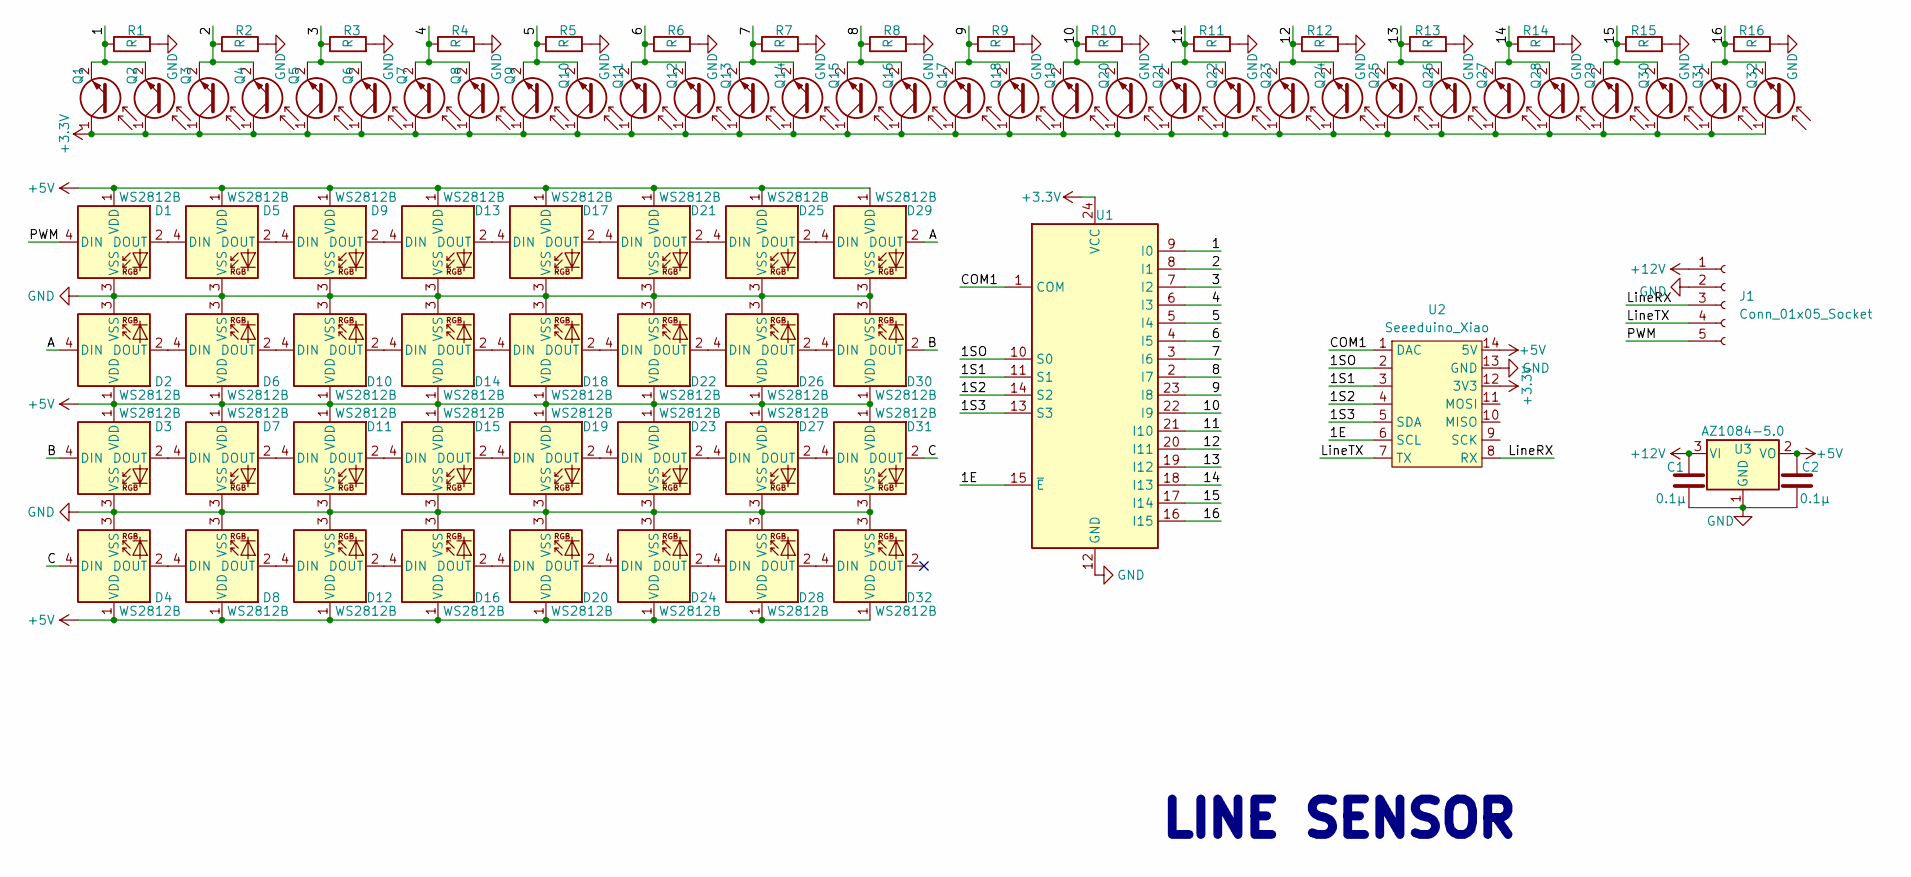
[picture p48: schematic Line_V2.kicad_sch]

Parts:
C1: 0.1μ; C_1210_3225Metric
C2: 0.1μ; C_0402_1005Metric; LCSC C1525
D1, D2, D3, D4, D5, D6, D7, D8, D9, D10, D11, D12, D13, D14, D15, D16, D17, D18, D19, D20, D21, D22, D23, D24, D25, D26, D27, D28, D29, D30, D31, D32: WS2812B; LED_WS2812B_PLCC4_5.0x5.0mm_P3.2mm; LCSC C965555
J1: Conn_01x05_Socket; PinHeader_1x05_P2.54mm_Vertical
Q1, Q2, Q3, Q4, Q5, Q6, Q7, Q8, Q9, Q10, Q11, Q12, Q13, Q14, Q15, Q16, Q17, Q18, Q19, Q20, Q21, Q22, Q23, Q24, Q25, Q26, Q27, Q28, Q29, Q30, Q31, Q32: Q_Photo_NPN; LED_D3.0mm
R1, R2, R3, R4, R5, R6, R7, R8, R9, R10, R11, R12, R13, R14, R15, R16: R; R_0603_1608Metric; LCSC C912493
U1: CD74HC4067SM; SSOP-24_5.3x8.2mm_P0.65mm; LCSC C98457
U2: Seeeduino_Xiao; seeeduinoXIAO
U3: AZ1084-5.0; TO-252-2

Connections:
+3.3V: Q1.1 (C), Q2.1 (C), Q3.1 (C), Q4.1 (C), Q5.1 (C), Q6.1 (C), Q7.1 (C), Q8.1 (C), Q9.1 (C), Q10.1 (C), Q11.1 (C), Q12.1 (C), Q13.1 (C), Q14.1 (C), Q15.1 (C), Q16.1 (C), Q17.1 (C), Q18.1 (C), Q19.1 (C), Q20.1 (C), Q21.1 (C), Q22.1 (C), Q23.1 (C), Q24.1 (C), Q25.1 (C), Q26.1 (C), Q27.1 (C), Q28.1 (C), Q29.1 (C), Q30.1 (C), Q31.1 (C), Q32.1 (C), U1.24 (VCC), U2.12 (3V3)
+5V: C2.2, D1.1 (VDD), D2.1 (VDD), D3.1 (VDD), D4.1 (VDD), D5.1 (VDD), D6.1 (VDD), D7.1 (VDD), D8.1 (VDD), D9.1 (VDD), D10.1 (VDD), D11.1 (VDD), D12.1 (VDD), D13.1 (VDD), D14.1 (VDD), D15.1 (VDD), D16.1 (VDD), D17.1 (VDD), D18.1 (VDD), D19.1 (VDD), D20.1 (VDD), D21.1 (VDD), D22.1 (VDD), D23.1 (VDD), D24.1 (VDD), D25.1 (VDD), D26.1 (VDD), D27.1 (VDD), D28.1 (VDD), D29.1 (VDD), D30.1 (VDD), D31.1 (VDD), D32.1 (VDD), U2.14 (5V), U3.2 (VO)
+12V: C1.2, J1.1, U3.3 (VI)
/1: Q1.2 (E), Q2.2 (E), R1.1, U1.9 (I0)
/1E: U1.15 (~E), U2.6 (SCL)
/1S1: U1.11 (S1), U2.3
/1S2: U1.14 (S2), U2.4
/1S3: U1.13 (S3), U2.5 (SDA)
/1SO: U1.10 (S0), U2.2
/2: Q3.2 (E), Q4.2 (E), R2.1, U1.8 (I1)
/3: Q5.2 (E), Q6.2 (E), R3.1, U1.7 (I2)
/4: Q7.2 (E), Q8.2 (E), R4.1, U1.6 (I3)
/5: Q9.2 (E), Q10.2 (E), R5.1, U1.5 (I4)
/6: Q11.2 (E), Q12.2 (E), R6.1, U1.4 (I5)
/7: Q13.2 (E), Q14.2 (E), R7.1, U1.3 (I6)
/8: Q15.2 (E), Q16.2 (E), R8.1, U1.2 (I7)
/9: Q17.2 (E), Q18.2 (E), R9.1, U1.23 (I8)
/10: Q19.2 (E), Q20.2 (E), R10.1, U1.22 (I9)
/11: Q21.2 (E), Q22.2 (E), R11.1, U1.21 (I10)
/12: Q23.2 (E), Q24.2 (E), R12.1, U1.20 (I11)
/13: Q25.2 (E), Q26.2 (E), R13.1, U1.19 (I12)
/14: Q27.2 (E), Q28.2 (E), R14.1, U1.18 (I13)
/15: Q29.2 (E), Q30.2 (E), R15.1, U1.17 (I14)
/16: Q31.2 (E), Q32.2 (E), R16.1, U1.16 (I15)
/A: D2.4 (DIN), D29.2 (DOUT)
/B: D3.4 (DIN), D30.2 (DOUT)
/C: D4.4 (DIN), D31.2 (DOUT)
/COM1: U1.1 (COM), U2.1 (DAC)
/LineRX: J1.3, U2.8 (RX)
/LineTX: J1.4, U2.7 (TX)
/PWM: D1.4 (DIN), J1.5
GND: C1.1, C2.1, D1.3 (VSS), D2.3 (VSS), D3.3 (VSS), D4.3 (VSS), D5.3 (VSS), D6.3 (VSS), D7.3 (VSS), D8.3 (VSS), D9.3 (VSS), D10.3 (VSS), D11.3 (VSS), D12.3 (VSS), D13.3 (VSS), D14.3 (VSS), D15.3 (VSS), D16.3 (VSS), D17.3 (VSS), D18.3 (VSS), D19.3 (VSS), D20.3 (VSS), D21.3 (VSS), D22.3 (VSS), D23.3 (VSS), D24.3 (VSS), D25.3 (VSS), D26.3 (VSS), D27.3 (VSS), D28.3 (VSS), D29.3 (VSS), D30.3 (VSS), D31.3 (VSS), D32.3 (VSS), J1.2, R1.2, R2.2, R3.2, R4.2, R5.2, R6.2, R7.2, R8.2, R9.2, R10.2, R11.2, R12.2, R13.2, R14.2, R15.2, R16.2, U1.12 (GND), U2.13 (GND), U3.1 (GND)
unnamed: D1.2 (DOUT), D5.4 (DIN)
unnamed: D2.2 (DOUT), D6.4 (DIN)
unnamed: D3.2 (DOUT), D7.4 (DIN)
unnamed: D4.2 (DOUT), D8.4 (DIN)
unnamed: D5.2 (DOUT), D9.4 (DIN)
unnamed: D6.2 (DOUT), D10.4 (DIN)
unnamed: D10.2 (DOUT), D14.4 (DIN)
unnamed: D7.2 (DOUT), D11.4 (DIN)
unnamed: D11.2 (DOUT), D15.4 (DIN)
unnamed: D8.2 (DOUT), D12.4 (DIN)
unnamed: D12.2 (DOUT), D16.4 (DIN)
unnamed: D9.2 (DOUT), D13.4 (DIN)
unnamed: D13.2 (DOUT), D17.4 (DIN)
unnamed: D14.2 (DOUT), D18.4 (DIN)
unnamed: D15.2 (DOUT), D19.4 (DIN)
unnamed: D16.2 (DOUT), D20.4 (DIN)
unnamed: D17.2 (DOUT), D21.4 (DIN)
unnamed: D18.2 (DOUT), D22.4 (DIN)
unnamed: D19.2 (DOUT), D23.4 (DIN)
unnamed: D20.2 (DOUT), D24.4 (DIN)
unnamed: D21.2 (DOUT), D25.4 (DIN)
unnamed: D22.2 (DOUT), D26.4 (DIN)
unnamed: D23.2 (DOUT), D27.4 (DIN)
unnamed: D24.2 (DOUT), D28.4 (DIN)
unnamed: D25.2 (DOUT), D29.4 (DIN)
unnamed: D26.2 (DOUT), D30.4 (DIN)
unnamed: D27.2 (DOUT), D31.4 (DIN)
unnamed: D28.2 (DOUT), D32.4 (DIN)

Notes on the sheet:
LINE SENSOR

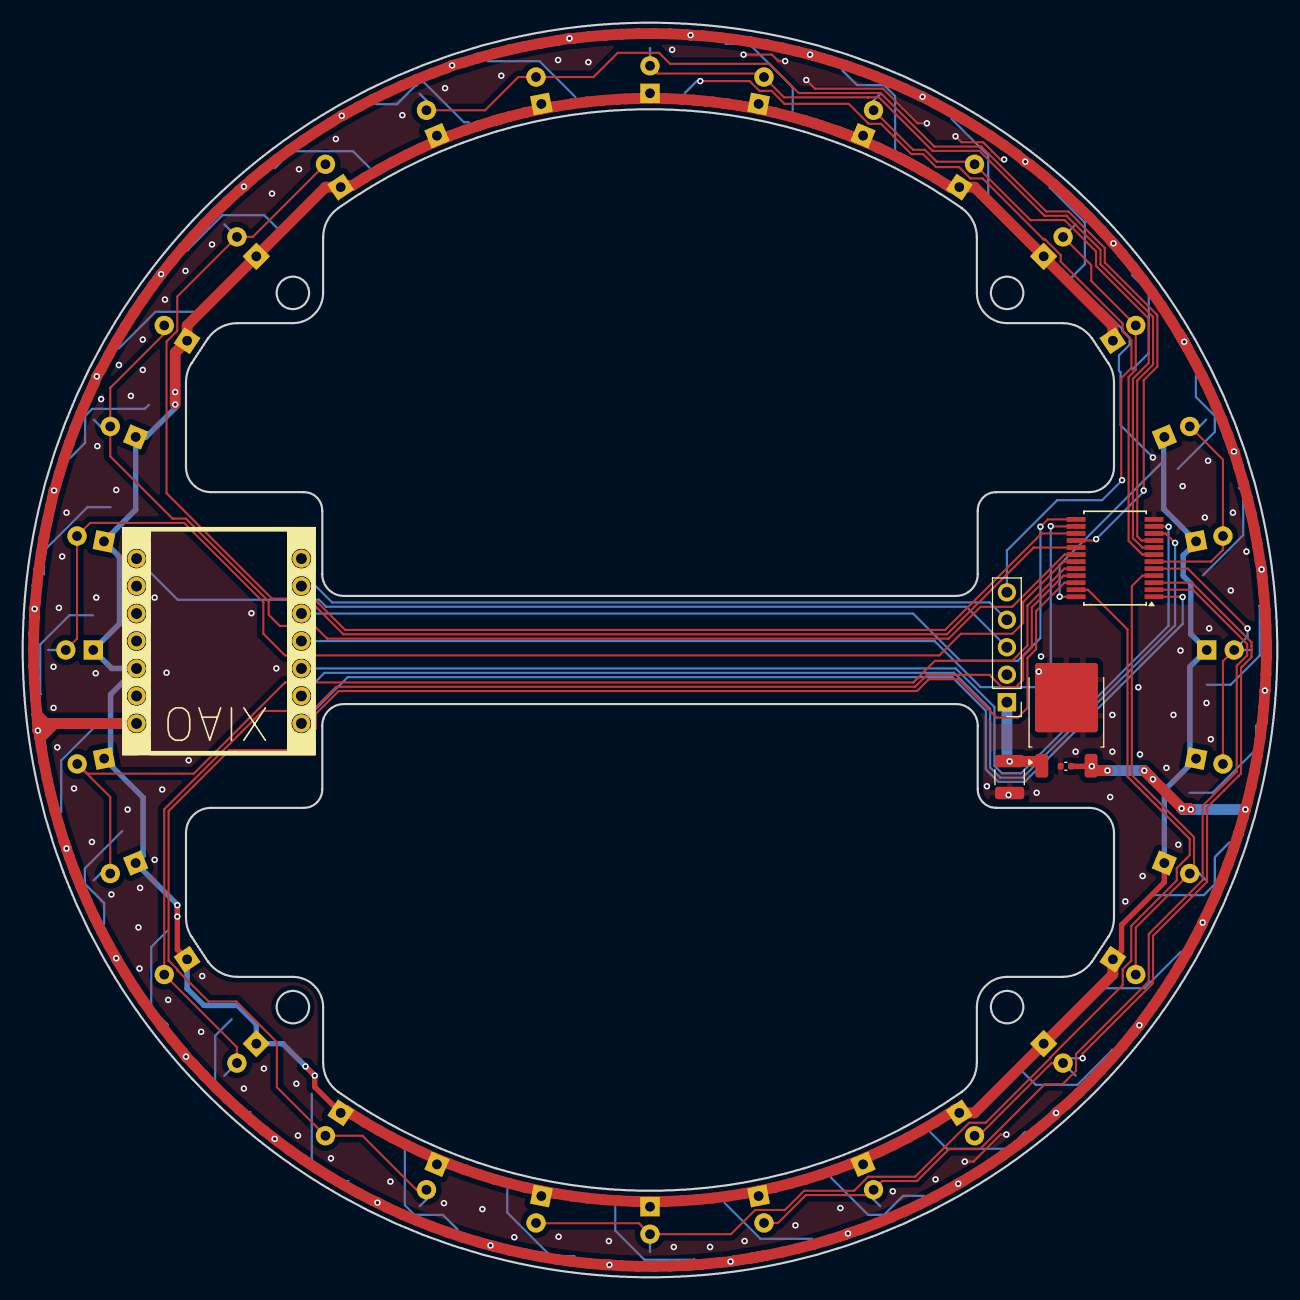
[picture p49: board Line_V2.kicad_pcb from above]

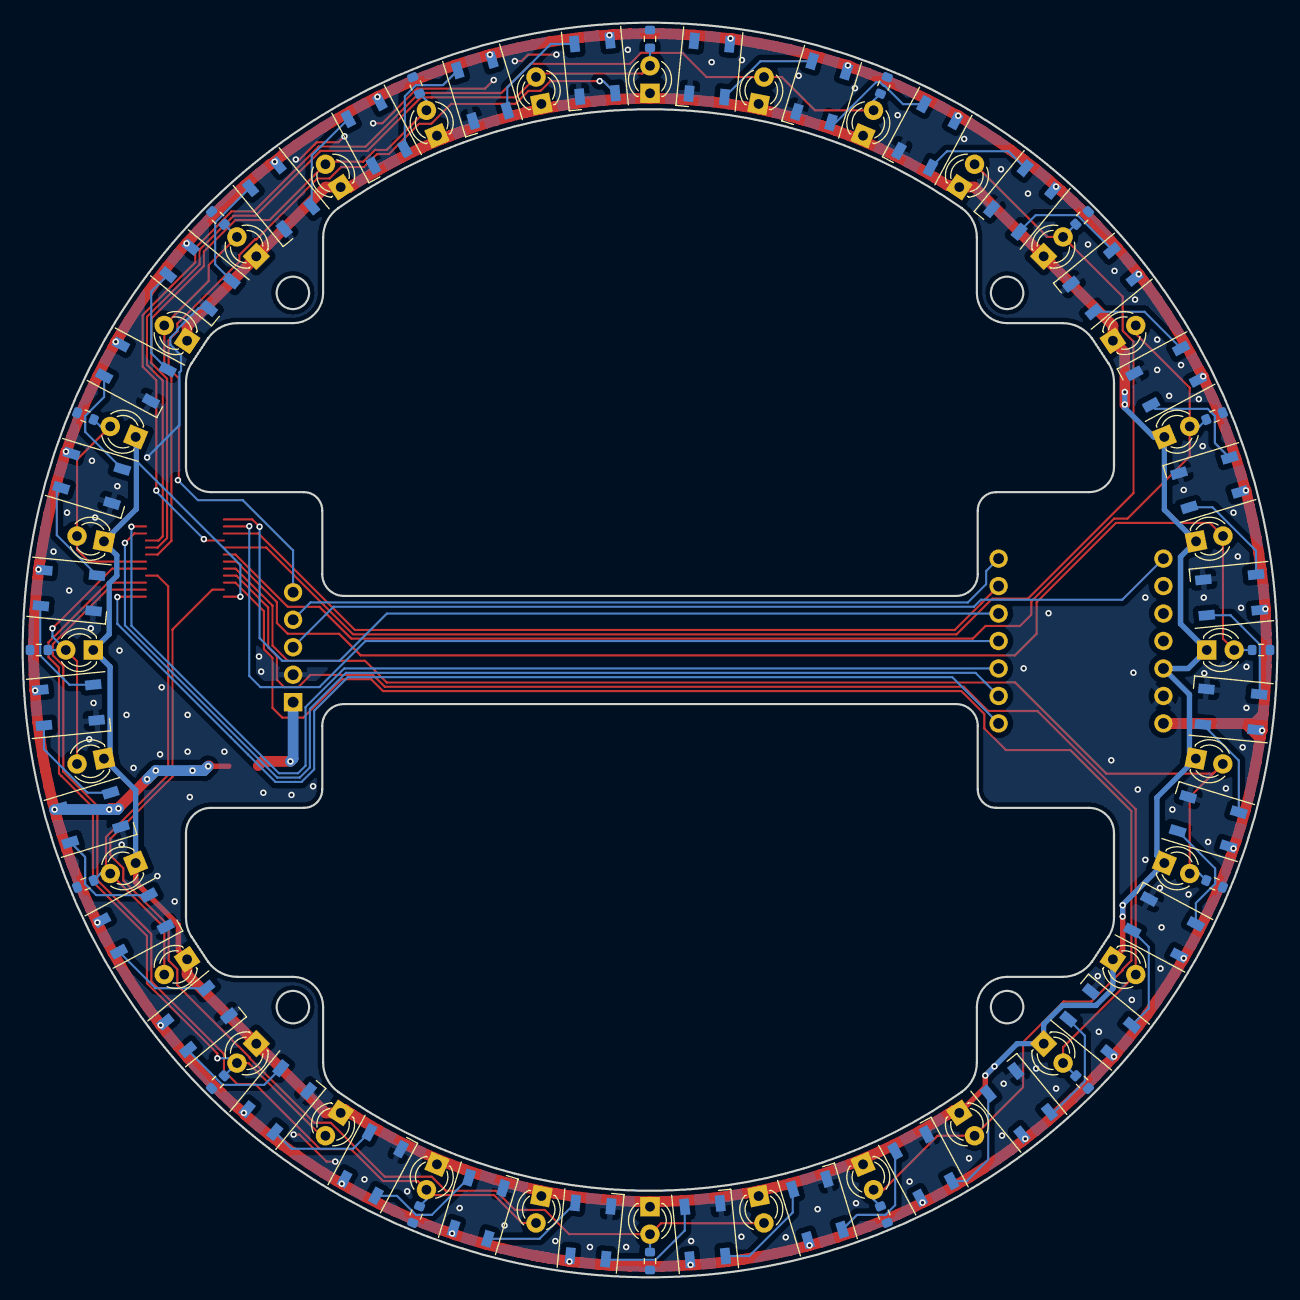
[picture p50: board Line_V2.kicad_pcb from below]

Board: 2 copper layers, 116.0 x 116.0 mm, 86 parts (80 on the bottom side), 60 nets.

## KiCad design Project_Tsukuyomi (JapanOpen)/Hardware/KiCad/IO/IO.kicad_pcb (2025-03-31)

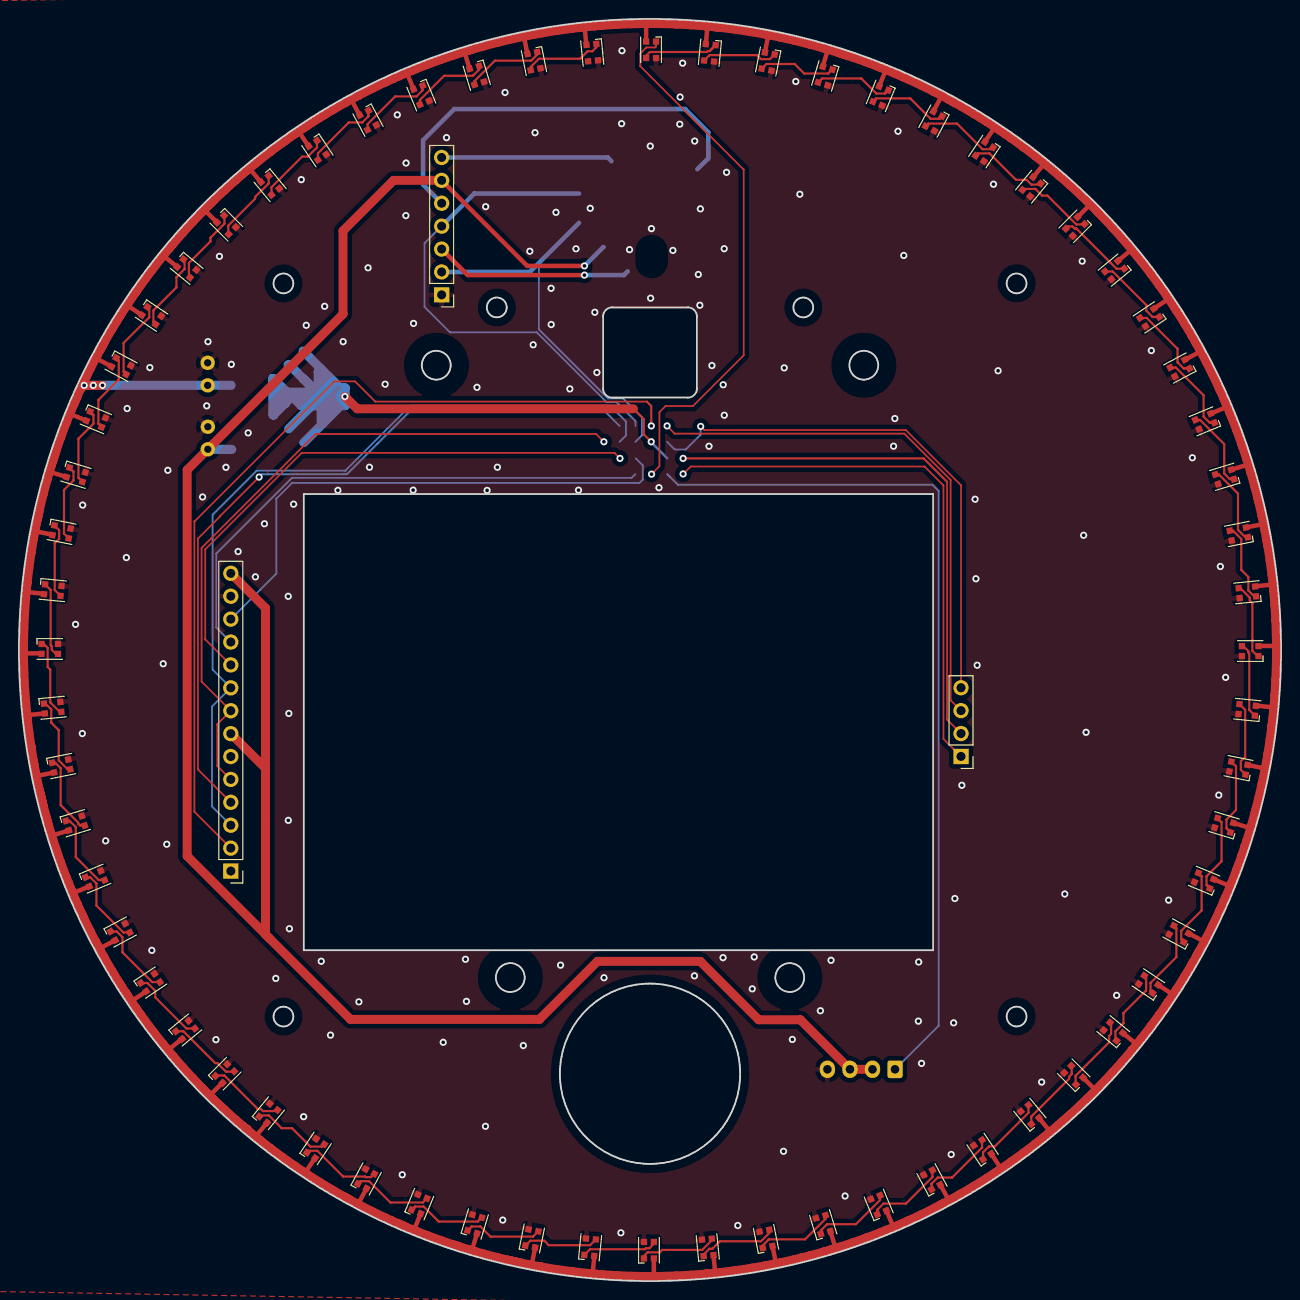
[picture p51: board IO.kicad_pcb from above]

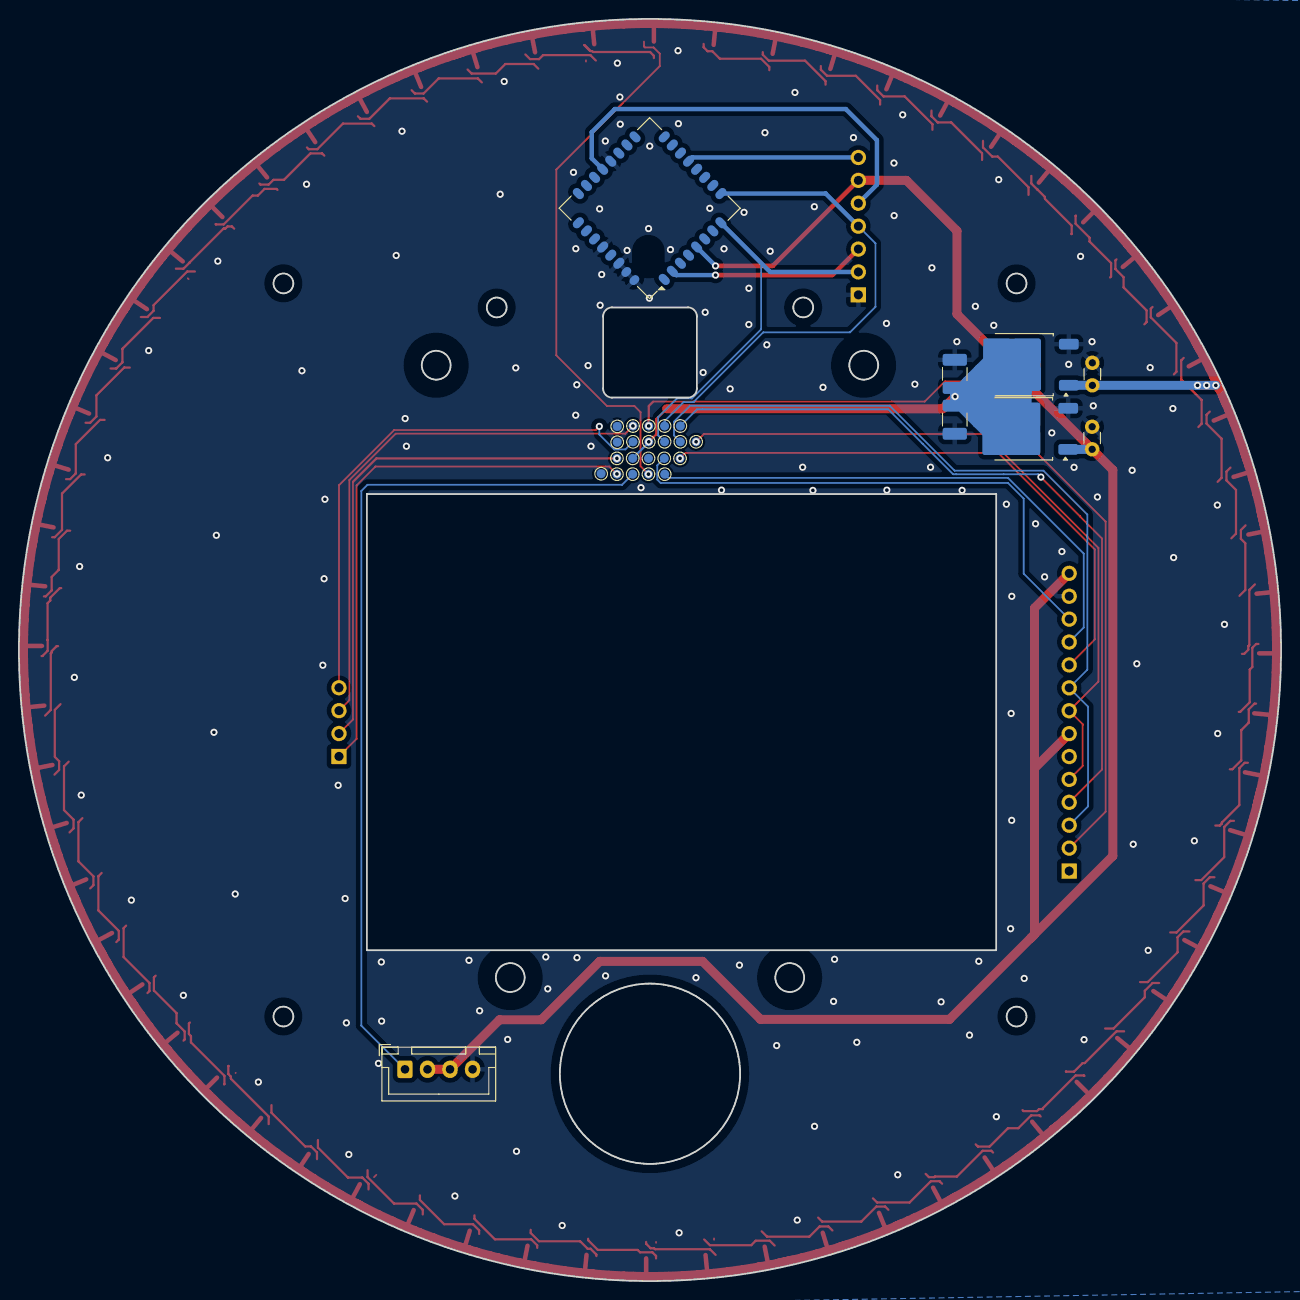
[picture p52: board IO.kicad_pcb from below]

Board: 2 copper layers, 140.0 x 140.0 mm, 96 parts (29 on the bottom side), 85 nets.

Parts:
C1, C3: C; C_1210_3225Metric_Pad1.33x2.70mm_HandSolder
C2, C4: C; C_Disc_D3.0mm_W1.6mm_P2.50mm
D1, D2, D3, D4, D5, D6, D7, D8, D9, D10, D11, D12, D13, D14, D15, D16, D17, D18, D19, D20, D21, D22, D23, D24, D25, D26, D27, D28, D29, D30, D31, D32, D33, D34, D35, D36, D37, D38, D39, D40, D41, D42, D43, D44, D45, D46, D47, D48, D49, D50, D51, D52, D53, D54, D55, D56, D57, D58, D59, D60, D61, D62, D63, D64: WS2812B; LED_WS2812B-2020_PLCC4_2.0x2.0mm
J1: Conn_01x14_Socket; PinHeader_1x14_P2.54mm_Vertical
J1#2, J2#2, J3#2, J4, J5#2, J6, J7, J8, J9, J10, J12, J13, J14, J15, J16, J17, J18, J19, J20, J21, J22: Conn_01x01_Socket; TestPoint_Pad_D1.0mm
J2: Conn_01x04_Socket; JST_XH_B4B-XH-A_1x04_P2.50mm_Vertical
J3: Conn_01x04_Socket; PinHeader_1x04_P2.54mm_Vertical
J5: Conn_01x07_Socket; PinHeader_1x07_P2.54mm_Vertical
U1: AZ1084-3.3; TO-252-2
U2: AZ1084-5.0; TO-252-2
U3: TWE-L-WX; MonoWireless_TWE-L-WX

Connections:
+3.3V: C2.1, J1.7, J1.14, J2.2, J2.3, J5.6, U1.2 (VO), U3.5 (VCC)
+5V: C4.1, D1.1 (VDD), D2.1 (VDD), D3.1 (VDD), D4.1 (VDD), D5.1 (VDD), D6.1 (VDD), D7.1 (VDD), D8.1 (VDD), D9.1 (VDD), D10.1 (VDD), D11.1 (VDD), D12.1 (VDD), D13.1 (VDD), D14.1 (VDD), D15.1 (VDD), D16.1 (VDD), D17.1 (VDD), D18.1 (VDD), D19.1 (VDD), D20.1 (VDD), D21.1 (VDD), D22.1 (VDD), D23.1 (VDD), D24.1 (VDD), D25.1 (VDD), D26.1 (VDD), D27.1 (VDD), D28.1 (VDD), D29.1 (VDD), D30.1 (VDD), D31.1 (VDD), D32.1 (VDD), D33.1 (VDD), D34.1 (VDD), D35.1 (VDD), D36.1 (VDD), D37.1 (VDD), D38.1 (VDD), D39.1 (VDD), D40.1 (VDD), D41.1 (VDD), D42.1 (VDD), D43.1 (VDD), D44.1 (VDD), D45.1 (VDD), D46.1 (VDD), D47.1 (VDD), D48.1 (VDD), D49.1 (VDD), D50.1 (VDD), D51.1 (VDD), D52.1 (VDD), D53.1 (VDD), D54.1 (VDD), D55.1 (VDD), D56.1 (VDD), D57.1 (VDD), D58.1 (VDD), D59.1 (VDD), D60.1 (VDD), D61.1 (VDD), D62.1 (VDD), D63.1 (VDD), D64.1 (VDD), U2.2 (VO)
+12V: C1.1, C3.1, J1#2.1, J12.1, U1.3 (VI), U2.3 (VI)
/A: D2.4 (DIN), D57.2 (DOUT)
/B: D3.4 (DIN), D58.2 (DOUT)
/C: D4.4 (DIN), D59.2 (DOUT)
/CS: J1.12, J15.1
/D: D5.4 (DIN), D60.2 (DOUT)
/DC: J1.10, J16.1
/E: D6.4 (DIN), D61.2 (DOUT)
/F: D7.4 (DIN), D62.2 (DOUT)
/G: D8.4 (DIN), D63.2 (DOUT)
/MISO: J1.2, J4.1
/MOSI: J1.3, J1.9, J7.1
/PRG: J5.3, U3.2 (DO1/PWM3)
/PWM: D1.4 (DIN), J13.1
/RESET: J1.11, J17.1
/RST: J5.5, U3.21 (~RESET)
/RXD: J3#2.1, J5.4, U3.9 (DIO7/RX)
/SCK: J1.5, J1.8, J8.1
/SD＿CS: J3.4, J5#2.1
/SD＿MISO: J3.2, J19.1
/SD＿MOSI: J3.3, J6.1
/SD＿SCK: J3.1, J20.1
/SET: J5.7, U3.13 (DIO12/DI1)
/START: J2.1, J18.1
/TXD: J2#2.1, J5.2, U3.8 (DIO6/TX)
/T_CS: J1.4, J9.1
GND: C1.2, C2.2, C3.2, C4.2, D1.3 (VSS), D2.3 (VSS), D3.3 (VSS), D4.3 (VSS), D5.3 (VSS), D6.3 (VSS), D7.3 (VSS), D8.3 (VSS), D9.3 (VSS), D10.3 (VSS), D11.3 (VSS), D12.3 (VSS), D13.3 (VSS), D14.3 (VSS), D15.3 (VSS), D16.3 (VSS), D17.3 (VSS), D18.3 (VSS), D19.3 (VSS), D20.3 (VSS), D21.3 (VSS), D22.3 (VSS), D23.3 (VSS), D24.3 (VSS), D25.3 (VSS), D26.3 (VSS), D27.3 (VSS), D28.3 (VSS), D29.3 (VSS), D30.3 (VSS), D31.3 (VSS), D32.3 (VSS), D33.3 (VSS), D34.3 (VSS), D35.3 (VSS), D36.3 (VSS), D37.3 (VSS), D38.3 (VSS), D39.3 (VSS), D40.3 (VSS), D41.3 (VSS), D42.3 (VSS), D43.3 (VSS), D44.3 (VSS), D45.3 (VSS), D46.3 (VSS), D47.3 (VSS), D48.3 (VSS), D49.3 (VSS), D50.3 (VSS), D51.3 (VSS), D52.3 (VSS), D53.3 (VSS), D54.3 (VSS), D55.3 (VSS), D56.3 (VSS), D57.3 (VSS), D58.3 (VSS), D59.3 (VSS), D60.3 (VSS), D61.3 (VSS), D62.3 (VSS), D63.3 (VSS), D64.3 (VSS), J1.13, J2.4, J5.1, J10.1, J21.1, J22.1, U1.1 (GND), U2.1 (GND), U3.20 (GND), U3.28 (GND), U3.30 (GND), U3.31 (GND), U3.32 (GND)
unnamed: D1.2 (DOUT), D9.4 (DIN)
unnamed: D2.2 (DOUT), D10.4 (DIN)
unnamed: D10.2 (DOUT), D18.4 (DIN)
unnamed: D3.2 (DOUT), D11.4 (DIN)
unnamed: D11.2 (DOUT), D19.4 (DIN)
unnamed: D4.2 (DOUT), D12.4 (DIN)
unnamed: D12.2 (DOUT), D20.4 (DIN)
unnamed: D5.2 (DOUT), D13.4 (DIN)
unnamed: D13.2 (DOUT), D21.4 (DIN)
unnamed: D6.2 (DOUT), D14.4 (DIN)
unnamed: D14.2 (DOUT), D22.4 (DIN)
unnamed: D7.2 (DOUT), D15.4 (DIN)
unnamed: D15.2 (DOUT), D23.4 (DIN)
unnamed: D8.2 (DOUT), D16.4 (DIN)
unnamed: D16.2 (DOUT), D24.4 (DIN)
unnamed: D9.2 (DOUT), D17.4 (DIN)
unnamed: D17.2 (DOUT), D25.4 (DIN)
unnamed: D18.2 (DOUT), D26.4 (DIN)
unnamed: D19.2 (DOUT), D27.4 (DIN)
unnamed: D20.2 (DOUT), D28.4 (DIN)
unnamed: D21.2 (DOUT), D29.4 (DIN)
unnamed: D22.2 (DOUT), D30.4 (DIN)
unnamed: D23.2 (DOUT), D31.4 (DIN)
unnamed: D24.2 (DOUT), D32.4 (DIN)
unnamed: D25.2 (DOUT), D33.4 (DIN)
unnamed: D26.2 (DOUT), D34.4 (DIN)
unnamed: D27.2 (DOUT), D35.4 (DIN)
unnamed: D28.2 (DOUT), D36.4 (DIN)
unnamed: D29.2 (DOUT), D37.4 (DIN)
unnamed: D30.2 (DOUT), D38.4 (DIN)
unnamed: D31.2 (DOUT), D39.4 (DIN)
unnamed: D32.2 (DOUT), D40.4 (DIN)
unnamed: D33.2 (DOUT), D41.4 (DIN)
unnamed: D34.2 (DOUT), D42.4 (DIN)
unnamed: D35.2 (DOUT), D43.4 (DIN)
unnamed: D36.2 (DOUT), D44.4 (DIN)
unnamed: D37.2 (DOUT), D45.4 (DIN)
unnamed: D38.2 (DOUT), D46.4 (DIN)
unnamed: D39.2 (DOUT), D47.4 (DIN)
unnamed: D40.2 (DOUT), D48.4 (DIN)
unnamed: D41.2 (DOUT), D49.4 (DIN)
unnamed: D42.2 (DOUT), D50.4 (DIN)
unnamed: D43.2 (DOUT), D51.4 (DIN)
unnamed: D44.2 (DOUT), D52.4 (DIN)
unnamed: D45.2 (DOUT), D53.4 (DIN)
unnamed: D46.2 (DOUT), D54.4 (DIN)
unnamed: D47.2 (DOUT), D55.4 (DIN)
unnamed: D48.2 (DOUT), D56.4 (DIN)
unnamed: D49.2 (DOUT), D57.4 (DIN)
unnamed: D50.2 (DOUT), D58.4 (DIN)
unnamed: D51.2 (DOUT), D59.4 (DIN)
unnamed: D52.2 (DOUT), D60.4 (DIN)
unnamed: D53.2 (DOUT), D61.4 (DIN)
unnamed: D54.2 (DOUT), D62.4 (DIN)
unnamed: D55.2 (DOUT), D63.4 (DIN)
unnamed: D56.2 (DOUT), D64.4 (DIN)

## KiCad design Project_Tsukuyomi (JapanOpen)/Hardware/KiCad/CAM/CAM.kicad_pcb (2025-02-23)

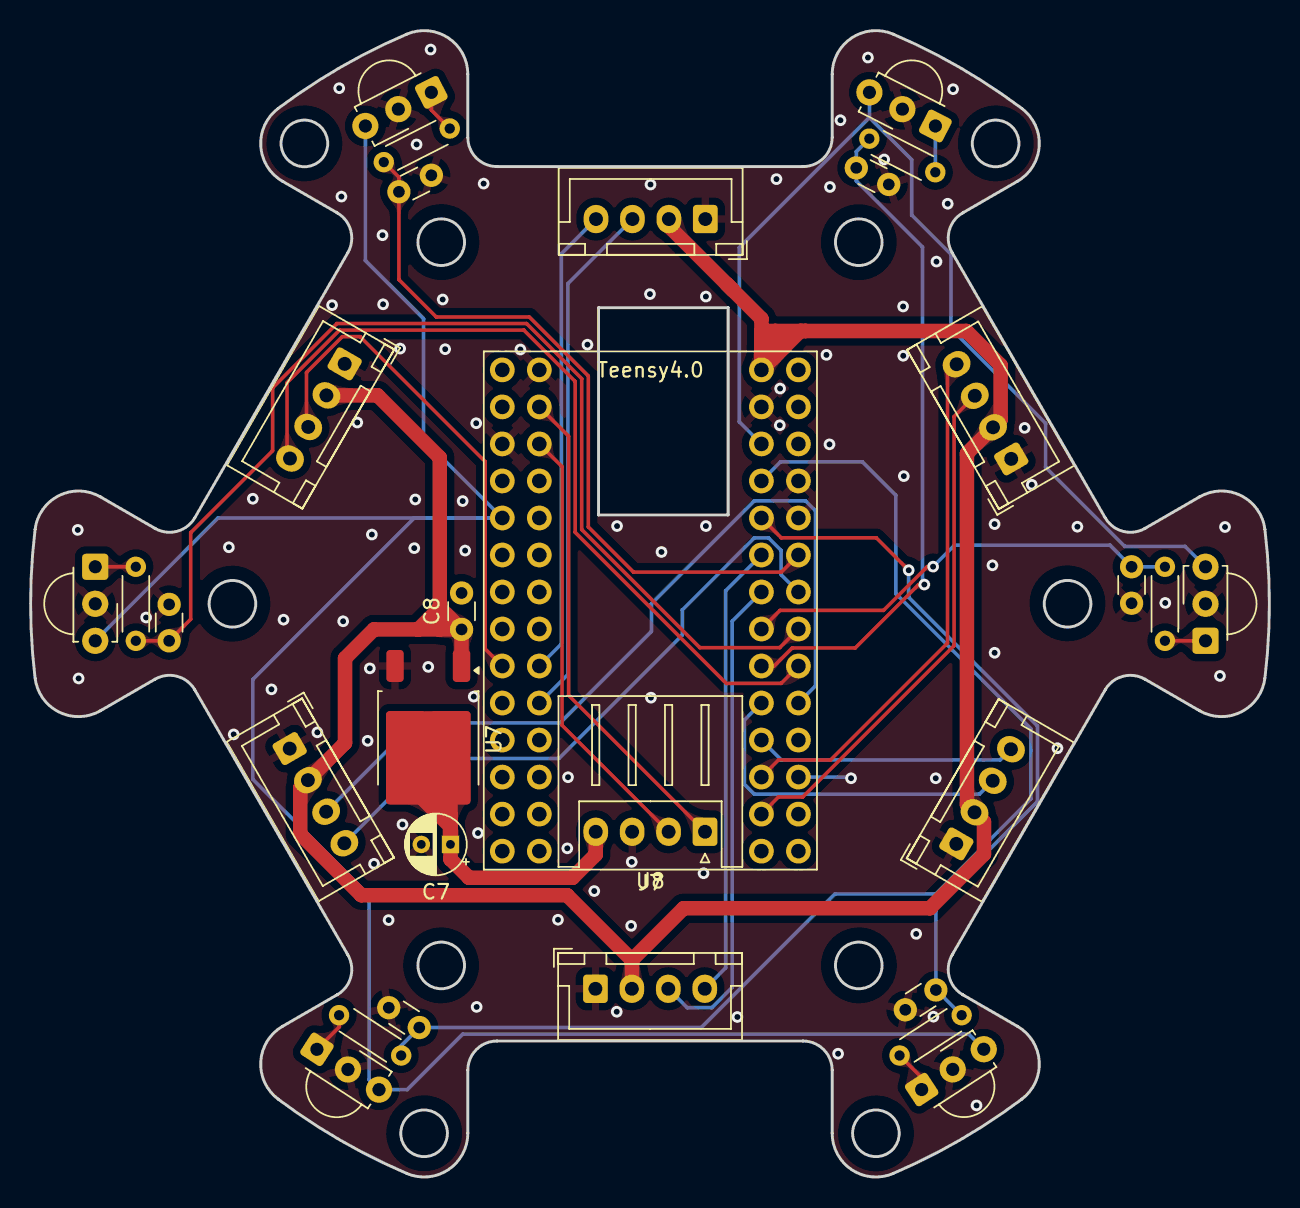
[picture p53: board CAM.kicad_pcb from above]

Board: 2 copper layers, 85.0 x 78.7 mm, 29 parts (0 on the bottom side), 30 nets.

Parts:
C1, C2, C3, C4, C5, C6: C_Small; C_Disc_D3.0mm_W1.6mm_P2.50mm
C7: C; CP_Radial_D4.0mm_P2.00mm
C8: C; C_Disc_D3.0mm_W1.6mm_P2.50mm
J1, J2, J3, J4, J5, J6: Conn_01x04_Socket; JST_XH_B4B-XH-A_1x04_P2.50mm_Vertical
J7: Conn_01x04_Socket; JST_XH_S4B-XH-A_1x04_P2.50mm_Horizontal
R1, R2, R3, R4, R5, R6: R; R_Axial_DIN0204_L3.6mm_D1.6mm_P5.08mm_Horizontal
U1, U2, U3, U4, U5, U6: TSSP58P38; Vishay_MINICAST-3Pin
U7: AZ1084-5.0; TO-252-2
U8: Teensy4.0; Teensy_Brakeout

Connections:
+3.3V: U1.3 (Vs), U2.3 (Vs), U3.3 (Vs), U4.3 (Vs), U5.3 (Vs), U6.3 (Vs), U8.31 (3V3)
+5V: C8.1, J1.2, J2.2, J3.2, J4.2, J5.2, J6.2, U7.2 (VO), U8.33 (VIN)
+12V: C7.1, J7.4, U7.3 (VI)
/CAM1RX: J1.4, U8.9 (7_RX2_OUT1A)
/CAM1TX: J1.3, U8.10 (8_TX2_IN1)
/CAM2RX: J2.4, U8.22 (15_A1_RX3_SPDIF_IN)
/CAM2TX: J2.3, U8.21 (14_A0_TX3_SPDIF_OUT)
/CAM3RX: J3.4, U8.23 (16_A2_RX4_SCL1)
/CAM3TX: J3.3, U8.24 (17_A3_TX4_SDA1)
/CAM4RX: J4.4, U8.28 (21_A7_RX5_BCLK1)
/CAM4TX: J4.3, U8.27 (20_A6_TX5_LRCLK1)
/CAM5RX: J5.4, U8.36 (25_A11_RX6_SDA2)
/CAM5TX: J5.3, U8.35 (24_A10_TX6_SCL2)
/CAM6RX: J6.4, U8.39 (28_RX7)
/CAM6TX: J6.3, U8.40 (29_TX7)
/CAMRX: J7.2, U8.3 (1_TX1_CTX2_MISO1)
/CAMTX: J7.1, U8.2 (0_RX1_CRX2_CS1)
/IR1: C1.1, R1.2, U8.25 (18_A4_SDA0)
/IR2: C2.1, R2.2, U8.26 (19_A5_SCL0)
/IR3: C3.1, R3.2, U8.29 (22_A8_CTX1)
/IR4: C4.1, R4.2, U8.30 (23_A9_CRX1_MCLK1)
/IR5: C5.1, R5.2, U8.37 (26_A12_MOSI1)
/IR6: C6.1, R6.2, U8.38 (27_A13_SCK1)
GND: C1.2, C2.2, C3.2, C4.2, C5.2, C6.2, C7.2, C8.2, J1.1, J2.1, J3.1, J4.1, J5.1, J6.1, J7.3, U1.2 (GND), U2.2 (GND), U3.2 (GND), U4.2 (GND), U5.2 (GND), U6.2 (GND), U7.1 (GND), U8.1 (GND)
unnamed: R1.1, U1.1 (OUT)
unnamed: R2.1, U2.1 (OUT)
unnamed: R3.1, U3.1 (OUT)
unnamed: R4.1, U4.1 (OUT)
unnamed: R5.1, U5.1 (OUT)
unnamed: R6.1, U6.1 (OUT)

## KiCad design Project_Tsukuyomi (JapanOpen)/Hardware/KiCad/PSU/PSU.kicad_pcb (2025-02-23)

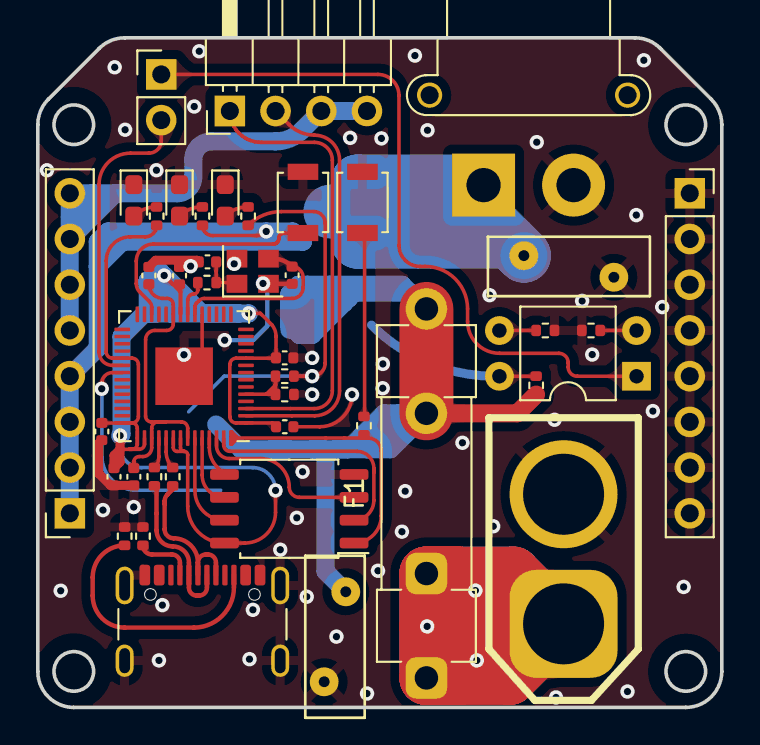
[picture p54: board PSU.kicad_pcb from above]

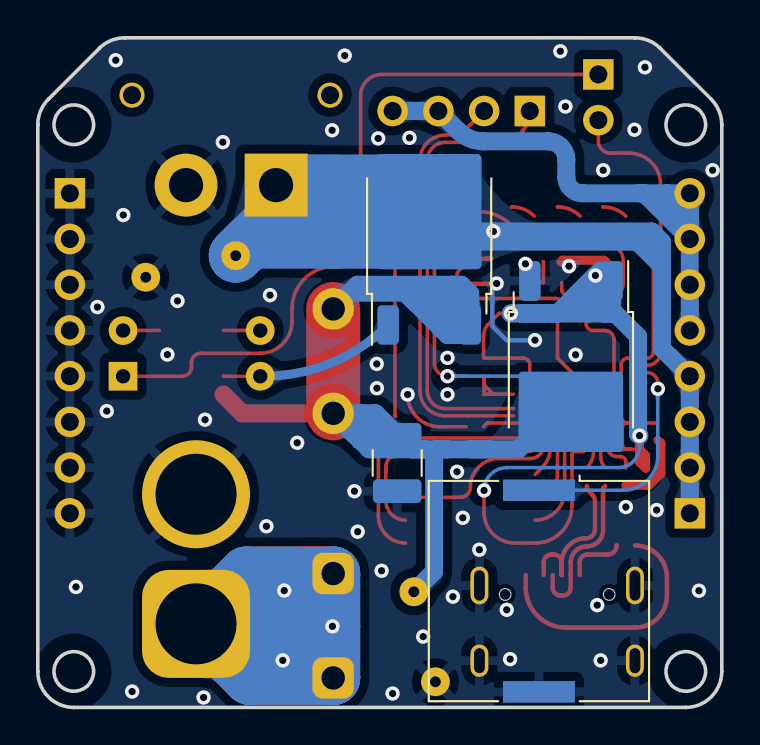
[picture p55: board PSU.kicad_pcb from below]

Board: 2 copper layers, 38.0 x 37.2 mm, 46 parts (4 on the bottom side), 36 nets.

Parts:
BT1: Battery; AMASS_XT60-M_1x02_P7.20mm_Vertical
BZ1: Buzzer; Buzzer_Murata_PKLCS1212E
C1, C2, C6, C7, C8, C9, C11: 0.1μ; C_0402_1005Metric
C4, C5: C_Small; C_0402_1005Metric
C10: 47μ; C_1210_3225Metric_Pad1.33x2.70mm_HandSolder
D1, D2, D3: LED; LED_0603_1608Metric_Pad1.05x0.95mm_HandSolder
F1: Fuse15A; Fuseholder_Clip-5x20mm_Littelfuse_520_Inline_P20.50x5.80mm_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
J1: USB_C_Receptacle_USB2.0; USB_C_Receptacle_GCT_USB4105-xx-A_16P_TopMnt_Horizontal
J2, J3: Conn_01x08_Socket; PinSocket_1x08_P2.54mm_Vertical
J4: Conn_01x04_Socket; PinHeader_1x04_P2.54mm_Horizontal
J5: Conn_01x02_Socket; AMASS_XT30PW-F_1x02_P2.50mm_Horizontal
J6: Conn_01x02_Socket; PinHeader_1x02_P2.54mm_Vertical
Q1: PMOS; TO-252-2
R1, R2, R3, R4, R9, R15, R16: 1k; R_0402_1005Metric
R5: 100; R_0402_1005Metric
R8: 3k; R_0402_1005Metric
R10, R11: 5.1k; R_0402_1005Metric
R12, R13: 27; R_0402_1005Metric
R14: 330; R_0402_1005Metric
RV1, RV2: Varistor; RV_Disc_D9mm_W3.3mm_P5mm
SW1, SW2: SW_Push; SW_SPST_B3U-1000P
U1: W25Q128JVS; SOIC-8_5.23x5.23mm_P1.27mm
U2: RP2040; QFN-56-1EP_7x7mm_P0.4mm_EP3.2x3.2mm
U3: SFH617A-1; DIP-4_W7.62mm
U4: AZ1084-5.0; TO-252-2
Y1: Crystal_GND24; Crystal_SMD_2520-4Pin_2.5x2.0mm

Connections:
+1V1: C1.2, C2.2, U2.23 (DVDD), U2.45 (VREG_VOUT), U2.50 (DVDD)
+3.3V: C6.2, C7.2, C8.2, C9.2, C11.1, R5.1, U1.8 (VCC), U2.1 (IOVDD), U2.10 (IOVDD), U2.22 (IOVDD), U2.33 (IOVDD), U2.42 (IOVDD), U2.43 (ADC_AVDD), U2.44 (VREG_IN), U2.48 (USB_VDD), U2.49 (IOVDD), U4.2 (VO)
+12V: J2.1, J2.2, J2.3, J2.4, J5.1, Q1.1 (D), R4.1, RV2.1
+48V: J2.5, J2.6, J2.7, J2.8, J4.3, J4.4
/BOOT: R1.1, SW2.1
/D+: R13.2, U2.47 (USB_DP)
/D-: R12.2, U2.46 (USB_DM)
/FET: J6.1, U3.1
/RUN: SW1.1, U2.26 (RUN)
/SW: J6.2, U2.34 (GPIO22)
/Temp+12v: C10.1, F1.2, Q1.3 (S), R3.1, R8.1, R16.1, RV1.1, U4.3 (VI)
/UART_RX: J4.2, U2.2 (GPIO0)
/UART_TX: J4.1, U2.3 (GPIO1)
/voltage: R8.2, R9.1, U2.5 (GPIO3)
GND: BT1.2 (-), BZ1.2 (+), C1.1, C2.1, C4.2, C5.1, C6.1, C7.1, C8.1, C9.1, C10.2, C11.2, D1.1 (K), D2.1 (K), D3.1 (K), J1.A1 (GND), J1.A12 (GND), J1.B1 (GND), J1.B12 (GND), J1.S1 (SHIELD), J3.1, J3.2, J3.3, J3.4, J3.5, J3.6, J3.7, J3.8, J5.2, R9.2, R10.2, R11.2, R14.1, R15.1, RV1.2, RV2.2, SW1.2, SW2.2, U1.4 (GND), U2.19 (TESTEN), U2.57 (GND), U4.1 (GND), Y1.2, Y1.4
unnamed: BT1.1 (+), F1.1
unnamed: BZ1.1 (-), U2.35 (GPIO23)
unnamed: C5.2, R2.2, Y1.1
unnamed: D1.2 (A), R3.2
unnamed: D2.2 (A), R4.2
unnamed: D3.2 (A), R5.2
unnamed: J1.A5 (CC1), R10.1
unnamed: J1.B5 (CC2), R11.1
unnamed: J1.A6 (D+), J1.B6 (D+), R13.1
unnamed: J1.A7 (D-), J1.B7 (D-), R12.1
unnamed: Q1.2 (G), R16.2, U3.4
unnamed: R14.2, U3.2
unnamed: R15.2, U3.3
unnamed: U1.6 (CLK), U2.52 (QSPI_SCLK)
unnamed: U1.5 (DI(IO0)), U2.53 (QSPI_SD0)
unnamed: U1.2 (DO(IO1)), U2.55 (QSPI_SD1)
unnamed: U1.3 (IO2), U2.54 (QSPI_SD2)
unnamed: U1.7 (IO3), U2.51 (QSPI_SD3)
unnamed: R1.2, U1.1 (~CS), U2.56 (QSPI_SS)
unnamed: C4.1, U2.20 (XIN), Y1.3
unnamed: R2.1, U2.21 (XOUT)

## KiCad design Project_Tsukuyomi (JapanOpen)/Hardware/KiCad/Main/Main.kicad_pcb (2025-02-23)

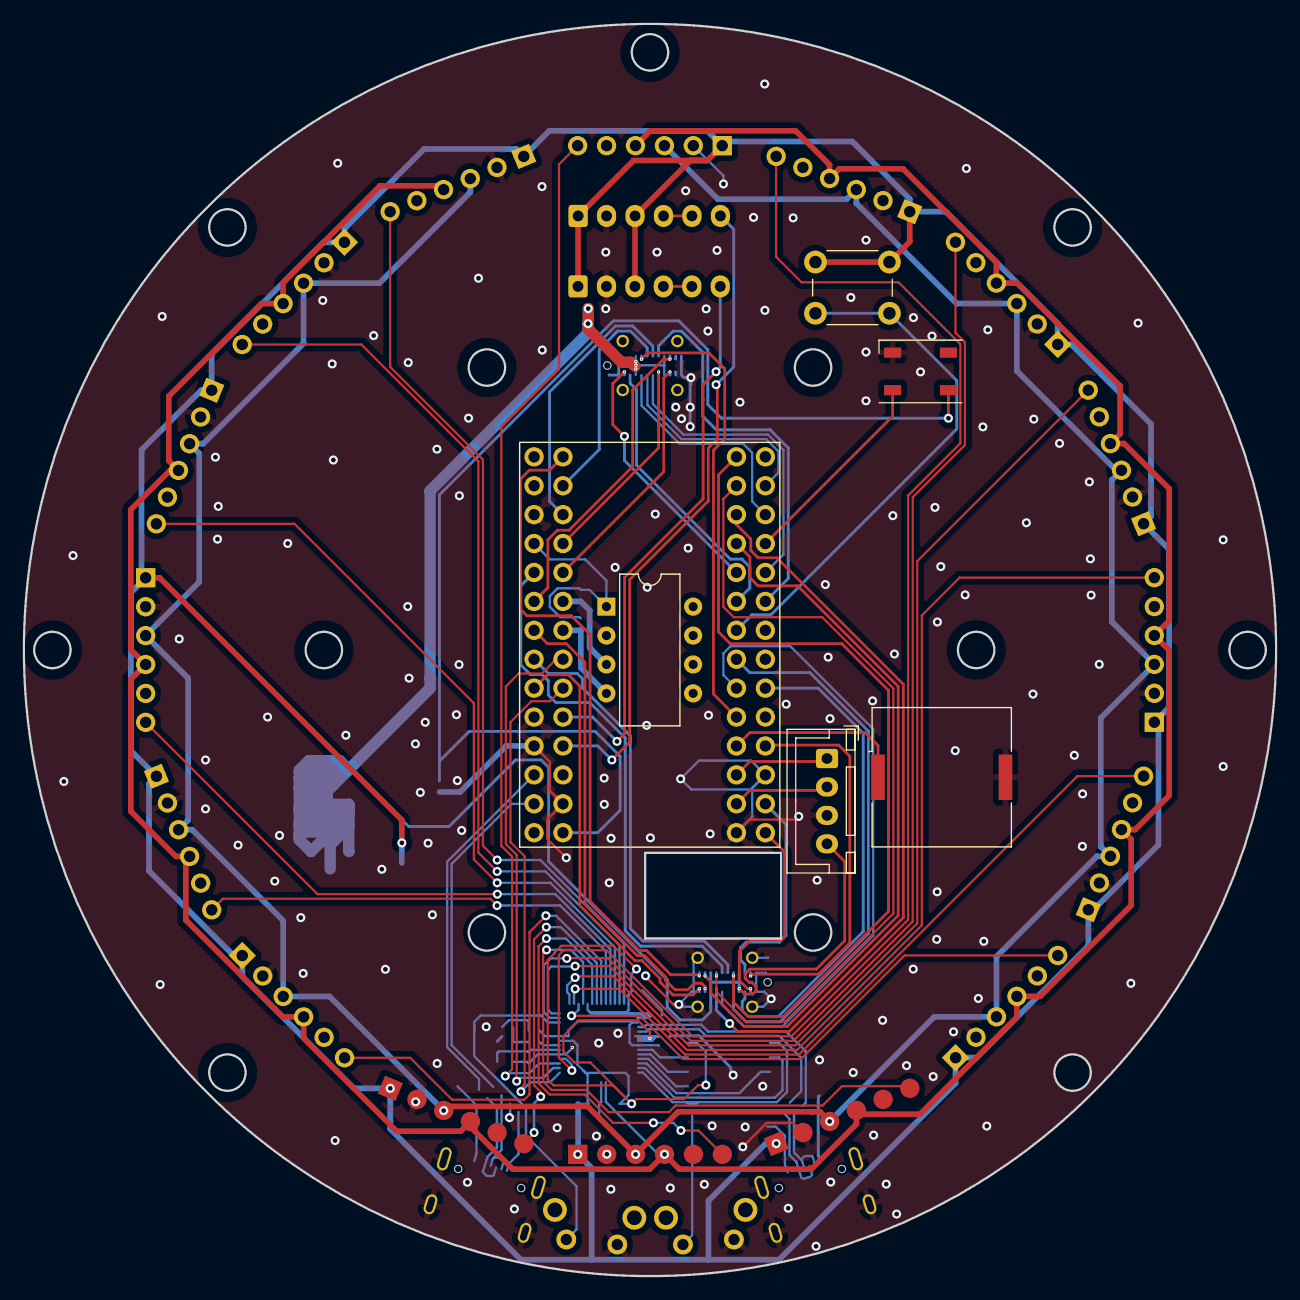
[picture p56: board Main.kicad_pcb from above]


Board: 2 copper layers, 110.0 x 110.0 mm, 61 parts (55 on the bottom side), 86 nets.

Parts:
BZ1: Buzzer; Buzzer_Murata_PKLCS1212E
C1, C2: C_Small; C_0402_1005Metric
C3, C4: C; C_1210_3225Metric_Pad1.33x2.70mm_HandSolder
C5, C6, C7, C8, C9, C10, C11, C12: C; C_0402_1005Metric
D1: WS2812B; LED_WS2812B_PLCC4_5.0x5.0mm_P3.2mm
J1, J20: USB_C_Receptacle_USB2.0; USB_C_Receptacle_GCT_USB4105-xx-A_16P_TopMnt_Horizontal
J2, J3, J4, J5, J6, J7, J8, J9, J10, J11, J12, J13, J15, J16, J17, J18: Conn_01x06_Socket; PinHeader_1x06_P2.54mm_Horizontal
J14, J19: UJ32-C-V-G-TH-5-P24-TR; USB_C_Receptacle_GCT_USB4115-03-C
J21: Conn_01x04_Socket; JST_XH_B4B-XH-A_1x04_P2.50mm_Vertical
J22, J23: Conn_01x06_Socket; JST_XH_B6B-XH-A_1x06_P2.50mm_Vertical
R1, R2: 1k; R_0402_1005Metric
R3, R4, R7, R8, R9, R10, R13, R14: 5.1k; R_0402_1005Metric
R5, R6, R11, R12: 27; R_0402_1005Metric
SW1, SW2: SW_Push; SW_Tactile_SPST_Angled_PTS645Vx31-2LFS
SW3: SW_Push; SW_PUSH_6mm
U1: W25Q128JVS; SOIC-8_5.23x5.23mm_P1.27mm
U2: RP2040; QFN-56-1EP_7x7mm_P0.4mm_EP3.2x3.2mm
U3: AZ1084-5.0; TO-252-2
U4: AZ1084-3.3; TO-252-2
U5: Teensy4.0; Teensy_Brakeout
U6: AE-BNO055-BO; CERDIP-8_W7.62mm_SideBrazed
Y1: Crystal_GND24; Crystal_SMD_2520-4Pin_2.5x2.0mm

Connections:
+1V1: C7.1, C8.1, U2.23 (DVDD), U2.45 (VREG_VOUT), U2.50 (DVDD)
+3.3V: C6.1, C9.1, C10.1, C11.1, C12.1, J2.1, J3.1, J4.1, J5.1, J6.1, J7.1, J8.1, J9.1, J10.1, J11.1, J12.1, J13.1, J15.1, J16.1, J17.1, J18.1, J22.1, J22.3, J23.1, J23.3, R7.2, R8.2, R13.2, R14.2, SW3.2, U1.8 (VCC), U2.1 (IOVDD), U2.10 (IOVDD), U2.22 (IOVDD), U2.33 (IOVDD), U2.42 (IOVDD), U2.43 (ADC_AVDD), U2.44 (VREG_IN), U2.48 (USB_VDD), U2.49 (IOVDD), U4.2 (VO), U5.31 (3V3), U6.0 (VIN)
+5V: C5.1, D1.1 (VDD), U3.2 (VO), U5.33 (VIN)
+12V: C3.1, C4.1, J14.A4 (VBUS), J14.A9 (VBUS), J14.B4 (VBUS), J14.B9 (VBUS), J19.A4 (VBUS), J19.A9 (VBUS), J19.B4 (VBUS), J19.B9 (VBUS), J21.4, U3.3 (VI), U4.3 (VI)
/1: J2.6, U2.17 (GPIO14)
/2: J6.6, U2.18 (GPIO15)
/3: J10.6, U2.27 (GPIO16)
/4: J15.6, U2.28 (GPIO17)
/5: J3.6, U2.29 (GPIO18)
/6: J7.6, U2.30 (GPIO19)
/7: J11.6, U2.31 (GPIO20)
/8: J16.6, U2.32 (GPIO21)
/9: J4.6, U2.34 (GPIO22)
/10: J8.6, U2.35 (GPIO23)
/11: J12.6, U2.36 (GPIO24)
/12: J17.6, U2.37 (GPIO25)
/13: J5.6, U2.38 (GPIO26_ADC0)
/14: J9.6, U2.39 (GPIO27_ADC1)
/15: J13.6, U2.40 (GPIO28_ADC2)
/16: J18.6, U2.41 (GPIO29_ADC3)
/BOOT: R1.1, SW2.1
/CAMRX: J21.2, U5.2 (0_RX1_CRX2_CS1)
/CAMTX: J21.1, U5.3 (1_TX1_CTX2_MISO1)
/CS: J19.B5 (CC2), U5.12 (10_CS_MQSR)
/D+: R6.2, U2.47 (USB_DP)
/D-: R5.2, U2.46 (USB_DM)
/DC: J19.B2 (SSTXP2), U5.38 (27_A13_SCK1)
/FET1: J14.A6 (DP1), U5.41 (30_CRX3)
/FET2: J14.A7 (DN1), U5.42 (31_CTX3)
/FET3: J14.A5 (CC1), U5.43 (32_OUT1B)
/LineRX: J14.B6 (DP2), U5.22 (15_A1_RX3_SPDIF_IN)
/LineTX: J14.B7 (DN2), U5.21 (14_A0_TX3_SPDIF_OUT)
/Line_NeoPixel: J14.B8 (SBU2), U5.5 (3_LRCLK2)
/MDRX: J14.A3 (SSTXN1), U5.9 (7_RX2_OUT1A)
/MDTX: J14.A2 (SSTXP1), U5.10 (8_TX2_IN1)
/MISO: J19.A5 (CC1), U5.14 (12_MISO_MQSL)
/MOSI: J19.A8 (SBU1), U5.13 (11_MOSI_CTX1)
/Main_SCL: R14.1, U5.26 (19_A5_SCL0), U6.3 (SCL)
/Main_SDA: R13.1, U5.25 (18_A4_SDA0), U6.2 (SDA)
/MouseRX: J14.B3 (SSTXN2), U5.39 (28_RX7)
/MouseTX: J14.B5 (CC2), U5.40 (29_TX7)
/NeoPixel: J19.B6 (DP2), U5.6 (4_BCLK2)
/RESET: J19.B3 (SSTXN2), U5.37 (26_A12_MOSI1)
/RUN: SW1.1, U2.26 (RUN)
/SCK: J19.A11 (SSRXP2), U5.20 (13_SCK_CRX1_LED)
/SCL: J2.3, J3.3, J4.3, J5.3, J6.3, J7.3, J8.3, J9.3, J10.3, J11.3, J12.3, J13.3, J15.3, J16.3, J17.3, J18.3, R7.1, U2.7 (GPIO5)
/SDA: J2.4, J3.4, J4.4, J5.4, J6.4, J7.4, J8.4, J9.4, J10.4, J11.4, J12.4, J13.4, J15.4, J16.4, J17.4, J18.4, R8.1, U2.6 (GPIO4)
/SD＿CS: J19.A2 (SSTXP1), U5.48 (36_CLK_CS2)
/SD＿MISO: J19.B11 (SSRXP1), U5.45 (34_DAT1_MISO2)
/SD＿MOSI: J19.A3 (SSTXN1), U5.46 (35_DAT0_MOSI2)
/SD＿SCK: J19.B10 (SSRXN1), U5.50 (37_CMD_SCK2)
/START: J19.B8 (SBU2), U5.7 (5_IN2)
/SUB: SW3.1, U5.8 (6_OUT1D)
/SUB_Ind: D1.4 (DIN), U5.44 (33_MCLK2)
/TD+: R12.2, U5.54 (D+)
/TD-: R11.2, U5.53 (D-)
/T_CS: J19.A10 (SSRXN2), U5.11 (9_OUT1C)
/ToF_RX: U2.15 (GPIO12), U5.28 (21_A7_RX5_BCLK1)
/ToF_TX: U2.16 (GPIO13), U5.27 (20_A6_TX5_LRCLK1)
/Touch_B: J23.6, U5.30 (23_A9_CRX1_MCLK1)
/Touch_F: J22.6, U5.29 (22_A8_CTX1)
/TweRX: J19.A6 (DP1), U5.36 (25_A11_RX6_SDA2)
/TweTX: J19.A7 (DN1), U5.35 (24_A10_TX6_SCL2)
/UART_RX: J14.A8 (SBU1), U5.23 (16_A2_RX4_SCL1)
/UART_TX: J14.A10 (SSRXN2), U5.24 (17_A3_TX4_SDA1)
GND: BZ1.2 (+), C1.2, C2.1, C3.2, C4.2, C5.2, C6.2, C7.2, C8.2, C9.2, C10.2, C11.2, C12.2, D1.3 (VSS), J1.A1 (GND), J1.A12 (GND), J1.B1 (GND), J1.B12 (GND), J1.S1 (SHIELD), J2.2, J3.2, J4.2, J5.2, J6.2, J7.2, J8.2, J9.2, J10.2, J11.2, J12.2, J13.2, J14.A1 (GND), J14.A12 (GND), J14.B1 (GND), J14.B12 (GND), J15.2, J16.2, J17.2, J18.2, J19.A1 (GND), J19.A12 (GND), J19.B1 (GND), J19.B12 (GND), J19.S1, J20.A1 (GND), J20.A12 (GND), J20.B1 (GND), J20.B12 (GND), J20.S1 (SHIELD), J21.3, J22.2, J23.2, R3.2, R4.2, R9.2, R10.2, SW1.2, SW2.2, U1.4 (GND), U2.19 (TESTEN), U2.57 (GND), U3.1 (GND), U4.1 (GND), U5.1 (GND), U6.1 (GND), Y1.2, Y1.4
unnamed: BZ1.1 (-), U5.4 (2_OUT2)
unnamed: C2.2, R2.2, Y1.1
unnamed: J1.A5 (CC1), R3.1
unnamed: J1.B5 (CC2), R4.1
unnamed: J1.A6 (D+), J1.B6 (D+), R6.1
unnamed: J1.A7 (D-), J1.B7 (D-), R5.1
unnamed: J20.A5 (CC1), R9.1
unnamed: J20.B5 (CC2), R10.1
unnamed: J20.A6 (D+), J20.B6 (D+), R12.1
unnamed: J20.A7 (D-), J20.B7 (D-), R11.1
unnamed: J22.4, J22.5
unnamed: J23.4, J23.5
unnamed: U1.6 (CLK), U2.52 (QSPI_SCLK)
unnamed: U1.5 (DI(IO0)), U2.53 (QSPI_SD0)
unnamed: U1.2 (DO(IO1)), U2.55 (QSPI_SD1)
unnamed: U1.3 (IO2), U2.54 (QSPI_SD2)
unnamed: U1.7 (IO3), U2.51 (QSPI_SD3)
unnamed: R1.2, U1.1 (~CS), U2.56 (QSPI_SS)
unnamed: C1.1, U2.20 (XIN), Y1.3
unnamed: R2.1, U2.21 (XOUT)

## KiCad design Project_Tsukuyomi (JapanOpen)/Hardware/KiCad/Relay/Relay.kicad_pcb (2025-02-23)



Board: 2 copper layers, 69.2 x 35.0 mm, 11 parts (2 on the bottom side), 23 nets.

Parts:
J1: UJ32-C-V-G-TH-5-P24-TR; USB_C_Receptacle_GCT_USB4115-03-C
J2: Conn_01x05_Socket; JST_XH_S5B-XH-A_1x05_P2.50mm_Horizontal
J3, J4: Conn_01x02_Socket; AMASS_XT30PW-M_1x02_P2.50mm_Horizontal
J5, J6: Conn_01x03_Socket; JST_XH_B3B-XH-A_1x03_P2.50mm_Vertical
J7: Conn_01x04_Socket; PinSocket_1x04_P2.54mm_Horizontal
J8: Conn_01x08_Socket; PinSocket_2x06_P2.54mm_Horizontal
J9: Conn_01x04_Socket; JST_XH_S4B-XH-A_1x04_P2.50mm_Horizontal
U1, U2: ESC_20A

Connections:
+12V: J1.A4 (VBUS), J1.A9 (VBUS), J1.B4 (VBUS), J1.B9 (VBUS), J2.1, J3.1, J4.1, J9.1, U1.1 (VDDM), U2.1 (VDDM)
+48V: J7.3, J7.4, J8.7
/BLDC1: J8.6, U1.3 (PWM)
/BLDC2: J8.8, U2.3 (PWM)
/FET1: J1.A6 (DP1), J8.3
/FET2: J1.A7 (DN1), J8.4
/FET3: J1.A5 (CC1), J8.5
/LineRX: J1.B6 (DP2), J2.3
/LineTX: J1.B7 (DN2), J2.4
/Line_NeoPixel: J1.B8 (SBU2), J2.5
/MDRX: J1.A3 (SSTXN1), J8.2
/MDTX: J1.A2 (SSTXP1), J8.1
/MouseRX: J1.B3 (SSTXN2), J9.3
/MouseTX: J1.B5 (CC2), J9.4
/OUT1A: J5.1, U1.6 (OUT_A)
/OUT1B: J5.2, U1.7 (OUT_B)
/OUT1C: J5.3, U1.8 (OUT_C)
/OUT2A: J6.1, U2.6 (OUT_A)
/OUT2B: J6.2, U2.7 (OUT_B)
/OUT2C: J6.3, U2.8 (OUT_C)
/UART_RX: J1.A8 (SBU1), J7.2
/UART_TX: J1.A10 (SSRXN2), J7.1
GND: J1.A1 (GND), J1.A12 (GND), J1.B1 (GND), J1.B12 (GND), J2.2, J3.2, J4.2, J9.2, U1.2 (GND), U1.5 (GND), U2.2 (GND), U2.5 (GND)

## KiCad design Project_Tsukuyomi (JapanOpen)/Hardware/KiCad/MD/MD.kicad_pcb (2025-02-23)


Board: 2 copper layers, 38.0 x 37.2 mm, 37 parts (0 on the bottom side), 43 nets.

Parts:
C1, C2: C_Small; C_0402_1005Metric
C3, C4, C5, C6, C7, C9, C11: 0.1μ; C_0402_1005Metric
C10: 0.1μ; C_1210_3225Metric_Pad1.33x2.70mm_HandSolder
D2, D3: LED; LED_0603_1608Metric_Pad1.05x0.95mm_HandSolder
J1: USB_C_Receptacle_USB2.0; USB_C_Receptacle_GCT_USB4105-xx-A_16P_TopMnt_Horizontal
J2, J3: Conn_01x08_Socket; PinHeader_1x08_P2.54mm_Vertical
J4, J5, J6, J7: Conn_01x02_Socket; JST_XH_B2B-XH-A_1x02_P2.50mm_Vertical
R1, R2: 5.1k; R_0402_1005Metric
R3, R4: 27; R_0402_1005Metric
R5, R6, R8: 1k; R_0402_1005Metric
R9: 100; R_0402_1005Metric
SW1, SW2: SW_Push; SW_SPST_B3U-1000P
U1: W25Q128JVS; SOIC-8_5.23x5.23mm_P1.27mm
U2: RP2040; QFN-56-1EP_7x7mm_P0.4mm_EP3.2x3.2mm
U3, U4, U5, U6: TB67H450FNG_EL; SOIC127P599X175-9N
U7: AZ1084-3.3; TO-252-2
Y1: Crystal_GND24; Crystal_SMD_2520-4Pin_2.5x2.0mm

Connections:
+1V1: C3.2, C4.2, U2.23 (DVDD), U2.45 (VREG_VOUT), U2.50 (DVDD)
+3.3V: C5.2, C6.2, C7.2, C9.2, C11.2, R9.1, U1.8 (VCC), U2.1 (IOVDD), U2.10 (IOVDD), U2.22 (IOVDD), U2.33 (IOVDD), U2.42 (IOVDD), U2.43 (ADC_AVDD), U2.44 (VREG_IN), U2.48 (USB_VDD), U2.49 (IOVDD), U3.4 (VREF), U4.4 (VREF), U5.4 (VREF), U6.4 (VREF), U7.2 (VO)
+12V: C10.2, J2.1, J2.2, J2.3, J2.4, J2.5, J2.6, J2.7, J2.8, R8.1, U3.5 (VM), U4.5 (VM), U5.5 (VM), U6.5 (VM), U7.3 (VO)
/BLDC1: J3.3, U2.13 (GPIO10)
/BLDC2: J3.4, U2.14 (GPIO11)
/BOOT: R5.1, SW2.1
/D+: R4.2, U2.47 (USB_DP)
/D-: R3.2, U2.46 (USB_DM)
/IN1A: U2.4 (GPIO2), U3.3 (IN1)
/IN1B: U2.5 (GPIO3), U3.2 (IN2)
/IN2A: U2.6 (GPIO4), U5.3 (IN1)
/IN2B: U2.7 (GPIO5), U5.2 (IN2)
/IN3A: U2.8 (GPIO6), U4.3 (IN1)
/IN3B: U2.9 (GPIO7), U4.2 (IN2)
/IN4A: U2.11 (GPIO8), U6.3 (IN1)
/IN4B: U2.12 (GPIO9), U6.2 (IN2)
/MDRX: J3.2, U2.2 (GPIO0)
/MDTX: J3.1, U2.3 (GPIO1)
/Motor1A: J4.1, U3.6 (OUT1)
/Motor1B: J4.2, U3.8 (OUT2)
/Motor2A: J5.1, U5.6 (OUT1)
/Motor2B: J5.2, U5.8 (OUT2)
/Motor3A: J6.1, U4.6 (OUT1)
/Motor3B: J6.2, U4.8 (OUT2)
/Motor4A: J7.1, U6.6 (OUT1)
/Motor4B: J7.2, U6.8 (OUT2)
/RUN: SW1.1, U2.26 (RUN)
GND: C1.2, C2.1, C3.1, C4.1, C5.1, C6.1, C7.1, C9.1, C10.1, C11.1, D2.1 (K), D3.1 (K), J1.A1 (GND), J1.A12 (GND), J1.B1 (GND), J1.B12 (GND), J1.S1 (SHIELD), J3.5, J3.6, J3.7, J3.8, R1.2, R2.2, SW1.2, SW2.2, U1.4 (GND), U2.19 (TESTEN), U2.57 (GND), U3.1 (GND), U3.7 (RS), U3.9 (GND), U4.1 (GND), U4.7 (RS), U4.9 (GND), U5.1 (GND), U5.7 (RS), U5.9 (GND), U6.1 (GND), U6.7 (RS), U6.9 (GND), U7.1 (GND), Y1.2, Y1.4
unnamed: C2.2, R6.2, Y1.1
unnamed: D2.2 (A), R8.2
unnamed: D3.2 (A), R9.2
unnamed: J1.A5 (CC1), R1.1
unnamed: J1.B5 (CC2), R2.1
unnamed: J1.A6 (D+), J1.B6 (D+), R4.1
unnamed: J1.A7 (D-), J1.B7 (D-), R3.1
unnamed: U1.6 (CLK), U2.52 (QSPI_SCLK)
unnamed: U1.5 (DI(IO0)), U2.53 (QSPI_SD0)
unnamed: U1.2 (DO(IO1)), U2.55 (QSPI_SD1)
unnamed: U1.3 (IO2), U2.54 (QSPI_SD2)
unnamed: U1.7 (IO3), U2.51 (QSPI_SD3)
unnamed: R5.2, U1.1 (~CS), U2.56 (QSPI_SS)
unnamed: C1.1, U2.20 (XIN), Y1.3
unnamed: R6.1, U2.21 (XOUT)

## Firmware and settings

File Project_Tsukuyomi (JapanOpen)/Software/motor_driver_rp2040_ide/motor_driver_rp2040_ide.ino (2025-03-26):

#include <Servo.h>

const int PIN_MOTOR_INA[4] = {2, 4, 6, 8};
const int PIN_MOTOR_INB[4] = {3, 5, 7, 9};

const int PIN_FRONT_DRIBBLER = 10;
const int PIN_BACK_DRIBBLER = 11;

class Motor{
  private:
    int _rotate;
    int _power;
  
  public:
    /// @brief モーターデータをセットします。
    /// @param power モーター駆動パワー(0~100%)
    /// @param rotate モーター回転方向(0:順転, 1:逆転)
    void set(int power, int rotate)
    {
      this->_power = power;
      this->_rotate = rotate;
    }
    
    /// @brief モーター駆動パワーを取得します。
    /// @return モーター駆動パワー(0-100%)
    int get_power()
    {
      return this->_power;
    }
  
    /// @brief モーター回転方向を取得します。
    /// @return モーター回転方向(0:順転, 1:逆転)
    int get_rotate()
    {
      return this->_rotate;
    }
};
  
Motor motors[4];
int f_bldc_power = 1050;
int b_bldc_power = 1050;

Servo front_bldc;
Servo back_bldc;

float motor_power;

int test;

void get_motor_data()
{
  String data = "aaa";

  if(Serial1.available() > 0)
  {
    data = Serial1.readStringUntil('\n');
    Serial.println(data);
  }

  if(data[0] != 'a')
  {
    int motor_a_rotate = ((String)data[0]).toInt();
    int motor_b_rotate = ((String)data[4]).toInt();
    int motor_c_rotate = ((String)data[8]).toInt();
    int motor_d_rotate = ((String)data[12]).toInt();

    int motor_a_power = ((String)data[1] + (String)data[2] + (String)data[3]).toInt();
    int motor_b_power = ((String)data[5] + (String)data[6] + (String)data[7]).toInt();
    int motor_c_power = ((String)data[9] + (String)data[10] + (String)data[11]).toInt();
    int motor_d_power = ((String)data[13] + (String)data[14] + (String)data[15]).toInt();

    f_bldc_power = 1000 + (((String)data[16] + (String)data[17] + (String)data[18]).toInt()) / 100.0 * 300.0;
    b_bldc_power = 1000 + (((String)data[19] + (String)data[20] + (String)data[21]).toInt()) / 100.0 * 300.0;

    motors[0].set(motor_a_power, motor_a_rotate);
    motors[1].set(motor_b_power, motor_b_rotate);
    motors[2].set(motor_c_power, motor_c_rotate);
    motors[3].set(motor_d_power, motor_d_rotate);
  }


  while(Serial1.available() > 0)
  {
    Serial1.readStringUntil('\n');
  }
}

void setup() {
  // put your setup code here, to run once:

  analogWriteRange(1023);

  for(int i = 0; i < 4; i++)
  {
    motors[i].set(0, 0);

    pinMode(PIN_MOTOR_INA[i], OUTPUT);
    pinMode(PIN_MOTOR_INB[i], OUTPUT);
  }

  Serial.begin(9600);

  Serial1.setTX(D0);
  Serial1.setRX(D1);
  Serial1.begin(115200);
  Serial1.setTimeout(10);

  front_bldc.attach(PIN_FRONT_DRIBBLER);
  back_bldc.attach(PIN_BACK_DRIBBLER);

  front_bldc.writeMicroseconds(2000);
  back_bldc.writeMicroseconds(2000);
  delay(500);
  front_bldc.writeMicroseconds(1000);
  back_bldc.writeMicroseconds(1000);
  delay(500);
  
  front_bldc.writeMicroseconds(1000);
  back_bldc.writeMicroseconds(1000);
  delay(3000);
}

void loop() {
  // put your main code here, to run repeatedly:

  get_motor_data();
  
  front_bldc.writeMicroseconds(f_bldc_power);
  back_bldc.writeMicroseconds(b_bldc_power);

  for(int i = 0; i < 4; i++)
  {
    if(motors[i].get_rotate() == 0)
    {
      if(motors[i].get_power() == 0)
      {
        analogWrite(PIN_MOTOR_INA[i], 0);
        analogWrite(PIN_MOTOR_INB[i], 0);
      }
      else
      {
        analogWrite(PIN_MOTOR_INA[i], (int)((motors[i].get_power()) / 100.0 * 1023.0));
        analogWrite(PIN_MOTOR_INB[i], 0);
      }
    }
    else
    {
      if(motors[i].get_power() == 0)
      {
        analogWrite(PIN_MOTOR_INA[i], 1023);
        analogWrite(PIN_MOTOR_INB[i], 1023);
      }
      else
      {
        analogWrite(PIN_MOTOR_INA[i], 0);
        analogWrite(PIN_MOTOR_INB[i], (int)((motors[i].get_power()) / 100.0 * 1023.0));
      }
    }
  }
}

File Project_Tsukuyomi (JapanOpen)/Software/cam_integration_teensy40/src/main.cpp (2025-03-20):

#include <Arduino.h>

//1~6個のカメラのデータ
//{ball_dir, ball_dis, goal_y_dir, goal_y_dis, goal_b_dir, goal_b_dis}
int cam_data[6][6] = { 
    {0, 0, 0, 0, 0, 0},
    {0, 0, 0, 0, 0, 0},
    {0, 0, 0, 0, 0, 0},
    {0, 0, 0, 0, 0, 0},
    {0, 0, 0, 0, 0, 0},
    {0, 0, 0, 0, 0, 0}
  };

HardwareSerialIMXRT serial_list[6] = {Serial2, Serial3, Serial4, Serial5, Serial6, Serial7};

int read_serial_type = 0;
int ball_deg = -1;

void read_cam_data(HardwareSerialIMXRT serial, int index)
{
  if(serial.available() > 0)
  {
    cam_data[index][0] = serial.readStringUntil('a').toInt();
    cam_data[index][1] = serial.readStringUntil('b').toInt();
    cam_data[index][2] = serial.readStringUntil('c').toInt();
    cam_data[index][3] = serial.readStringUntil('d').toInt();
    cam_data[index][4] = serial.readStringUntil('e').toInt();
    cam_data[index][5] = serial.readStringUntil('f').toInt();
  }
}

void setup() {
  // put your setup code here, to run once:

  Serial.begin(9600);

  Serial1.begin(115200);
  Serial1.setTimeout(10);

  Serial2.begin(115200);
  Serial2.setTimeout(5);
  Serial3.begin(115200);
  Serial3.setTimeout(5);
  Serial4.begin(115200);
  Serial4.setTimeout(5);
  Serial5.begin(115200);
  Serial5.setTimeout(5);
  Serial6.begin(115200);
  Serial6.setTimeout(5);
  Serial7.begin(115200);
  Serial7.setTimeout(5);
}

int calculate_average_dis(int data_index) 
{
  int sum = 0;
  int count = 0;


  for (int i = 0; i < 6; i++) 
  {
      // cam_data[i][0] が 500 でない場合にのみ sum に加算
      if (cam_data[i][data_index] != 500)
      {
          sum += cam_data[i][data_index];  // cam_data[i][0] を足す
          count++;
      }
  }

  return sum / count;
}

int calculate_average(int data_index) 
{
  int sum = 0;

  int count = 0;

  for (int i = 0; i < 6; i++) 
  {
      // cam_data[i][0] が 500 でない場合にのみ sum に加算
      if (cam_data[i][data_index] != 500)
      {
          sum += cam_data[i][data_index];  // cam_data[i][0] を足す
          count++;
      }
  }

  if (count > 0) 
  {
    // 平均を計算
    if((cam_data[0][data_index] != 500 && cam_data[5][data_index] != 500)||((cam_data[1][data_index] != 500 && cam_data[5][data_index] != 500)))
    {
      if((cam_data[0][data_index] != 500 && cam_data[1][data_index] != 500 && cam_data[5][data_index] != 500))
      {
        float average = (float)(sum + 360 + 360) / count ;
       
          if(average > 720)
          {
            return ((((((int)(average))))) + 315) % 720;
          }
          else
          {
            return ((((((int)(average))))) + 315) % 360;
          }
        
      }
      else
      {
        float average = (float)(sum + 360) / count ;
        return ((((((int)(average))))) + 315) % 360;
      }
  
      
    }
    else if(((cam_data[0][data_index] != 500 && cam_data[1][data_index] != 500) && cam_data[5][data_index] != 500)||((cam_data[0][data_index] != 500 && cam_data[1][data_index] != 500) && cam_data[5][data_index] != 500))
    {
      float average = (float)(sum + 360 * 2) / count ;
  
      return ((((((int)(average))))) + 315) % 360;
    }
    else
    {
      float average = (float)sum / count ;
  
      return ((int)(average) + 315) % 360 ;  // 余りが360未満の場合、平均をそのまま整数で返す
    }
  } 
  else 
  {
    return -1;  // データがなければ -1 を返す
  }
}




int test = 0;

void loop() {
  if(Serial2.available() > 0)
  {
    cam_data[0][0] = Serial2.readStringUntil('a').toInt();
    cam_data[0][1] = Serial2.readStringUntil('b').toInt();
    cam_data[0][2] = Serial2.readStringUntil('c').toInt();
    cam_data[0][3] = Serial2.readStringUntil('d').toInt();
    cam_data[0][4] = Serial2.readStringUntil('e').toInt();
    cam_data[0][5] = Serial2.readStringUntil('f').toInt();
  }

  if(Serial3.available() > 0)
  {
    cam_data[1][0] = Serial3.readStringUntil('a').toInt();
    cam_data[1][1] = Serial3.readStringUntil('b').toInt();
    cam_data[1][2] = Serial3.readStringUntil('c').toInt();
    cam_data[1][3] = Serial3.readStringUntil('d').toInt();
    cam_data[1][4] = Serial3.readStringUntil('e').toInt();
    cam_data[1][5] = Serial3.readStringUntil('f').toInt();

    cam_data[1][0] = cam_data[1][0] == 500 ? 500 : cam_data[1][0] + 60;
    cam_data[1][2] = cam_data[1][2] == 500 ? 500 : cam_data[1][2] + 60;
    cam_data[1][4] = cam_data[1][4] == 500 ? 500 : cam_data[1][4] + 60;
  }

  if(Serial4.available() > 0)
  {
    cam_data[2][0] = Serial4.readStringUntil('a').toInt();
    cam_data[2][1] = Serial4.readStringUntil('b').toInt();
    cam_data[2][2] = Serial4.readStringUntil('c').toInt();
    cam_data[2][3] = Serial4.readStringUntil('d').toInt();
    cam_data[2][4] = Serial4.readStringUntil('e').toInt();
    cam_data[2][5] = Serial4.readStringUntil('f').toInt();

    cam_data[2][0] = cam_data[2][0] == 500 ? 500 : cam_data[2][0] + 60 * 2;
    cam_data[2][2] = cam_data[2][2] == 500 ? 500 : cam_data[2][2] + 60 * 2;
    cam_data[2][4] = cam_data[2][4] == 500 ? 500 : cam_data[2][4] + 60 * 2;
  }

  if(Serial5.available() > 0)
  {
    cam_data[3][0] = Serial5.readStringUntil('a').toInt();
    cam_data[3][1] = Serial5.readStringUntil('b').toInt();
    cam_data[3][2] = Serial5.readStringUntil('c').toInt();
    cam_data[3][3] = Serial5.readStringUntil('d').toInt();
    cam_data[3][4] = Serial5.readStringUntil('e').toInt();
    cam_data[3][5] = Serial5.readStringUntil('f').toInt();

    cam_data[3][0] = cam_data[3][0] == 500 ? 500 : cam_data[3][0] + 60 * 3;
    cam_data[3][2] = cam_data[3][2] == 500 ? 500 : cam_data[3][2] + 60 * 3;
    cam_data[3][4] = cam_data[3][4] == 500 ? 500 : cam_data[3][4] + 60 * 3;
  }

  if(Serial6.available() > 0)
  {
    cam_data[4][0] = Serial6.readStringUntil('a').toInt();
    cam_data[4][1] = Serial6.readStringUntil('b').toInt();
    cam_data[4][2] = Serial6.readStringUntil('c').toInt();
    cam_data[4][3] = Serial6.readStringUntil('d').toInt();
    cam_data[4][4] = Serial6.readStringUntil('e').toInt();
    cam_data[4][5] = Serial6.readStringUntil('f').toInt();

    cam_data[4][0] = cam_data[4][0] == 500 ? 500 : cam_data[4][0] + 60 * 4;
    cam_data[4][2] = cam_data[4][2] == 500 ? 500 : cam_data[4][2] + 60 * 4;
    cam_data[4][4] = cam_data[4][4] == 500 ? 500 : cam_data[4][4] + 60 * 4;
  }

  if(Serial7.available() > 0)
  {
    cam_data[5][0] = Serial7.readStringUntil('a').toInt();
    cam_data[5][1] = Serial7.readStringUntil('b').toInt();
    cam_data[5][2] = Serial7.readStringUntil('c').toInt();
    cam_data[5][3] = Serial7.readStringUntil('d').toInt();
    cam_data[5][4] = Serial7.readStringUntil('e').toInt();
    cam_data[5][5] = Serial7.readStringUntil('f').toInt();

    cam_data[5][0] = cam_data[5][0] == 500 ? 500 : cam_data[5][0] + 60 * 5;
    cam_data[5][2] = cam_data[5][2] == 500 ? 500 : cam_data[5][2] + 60 * 5;
    cam_data[5][4] = cam_data[5][4] == 500 ? 500 : cam_data[5][4] + 60 * 5;
  }

  read_serial_type = (read_serial_type + 1) % 6;

  for(int i = 0; i < 6; i++)
  {
    Serial.print(cam_data[i][2]);
    Serial.print("\t");
  }

  //Serial.println(read_serial_type);
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

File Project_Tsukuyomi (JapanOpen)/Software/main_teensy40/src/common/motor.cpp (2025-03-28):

#include <Arduino.h>    

#include "sensors_variables.hpp"
#include "motor.hpp"

#define GYRO_PGAIN 0.98
#define GYRO_DGAIN 3.5
#define GOAL_PGAIN 0.3
#define GOAL_DGAIN 2.0

#define PID_MAX 80
#define PID_MOVING_MAX 20
#define PID_DIFF_MAX 85

int pid_value;

int pid_deviation;
int pid_previous_deviation;

int power_f_bldc;
int power_b_bldc;

void motor_set_bldc(int f_power, int b_power)
{
    power_f_bldc = f_power;
    power_b_bldc = b_power;
}

void init_motor()
{
    Serial2.begin(115200);
    Serial2.setTimeout(10);
}

void pid_gyro()
{
    int p_value = 0, d_value = 0;
    int gyro_value = gyro_deg;
    gyro_value = gyro_value > 180 ? gyro_value - 360 : gyro_value;
    
    p_value = gyro_value;

    pid_deviation = gyro_value;
    d_value = pid_deviation - pid_previous_deviation;
    pid_previous_deviation = gyro_value;

    pid_value = p_value * GYRO_PGAIN + d_value * GYRO_DGAIN;

    if(pid_value < 0)
    {
        if(pid_value < -PID_MAX)
        {
            pid_value = -PID_MAX;
        }
    }
    else
    {
        if(pid_value > PID_MAX)
        {
            pid_value = PID_MAX;
        }
    }
}

void pid_camera(int value)
{
    int p_value = 0, d_value = 0;
    int gyro_value = value;
    gyro_value = gyro_value > 180 ? -(gyro_value - 360) : -gyro_value;
    
    p_value = gyro_value;

    pid_deviation = gyro_value;
    d_value = pid_deviation - pid_previous_deviation;
    pid_previous_deviation = gyro_value;

    pid_value = p_value * GOAL_PGAIN + d_value * GOAL_DGAIN;
    
    if(pid_value < 0)
    {
        if(pid_value < -PID_MAX)
        {
            pid_value = -PID_MAX;
        }
    }
    else
    {
        if(pid_value > PID_MAX)
        {
            pid_value = PID_MAX;
        }
    }
}

float get_max_value_in_array(float* ar, int ar_cnt)
{
    float ret = 0;

    for(int i = 0; i < ar_cnt; i++)
    {
        if(abs(ar[i]) > ret)
        {
            ret = abs(ar[i]);
        }
    }   

    return ret;
}

void motor_break()
{
    Serial2.println("1000100010001000");
}

void motor_direct_drive(int a, int b, int c, int d, bool a_b, bool b_b , bool c_b, bool d_b)
{
    String power_a = String(min(max(abs(a), 0), 100));
    String power_b = String(min(max(abs(b), 0), 100));
    String power_c = String(min(max(abs(c), 0), 100));
    String power_d = String(min(max(abs(d), 0), 100));
    String power_b_f = String(min(max(abs(power_f_bldc), 0), 100));
    String power_b_b = String(min(max(abs(power_b_bldc), 0), 100));

    if(abs(a) <= 9)
    {
        power_a = "00" + power_a;
    }
    else if(abs(a) <= 99)
    {
        power_a = "0" + power_a;
    }

    if(abs(b) <= 9)
    {
        power_b = "00" + power_b;
    }
    else if(abs(b) <= 99)
    {
        power_b = "0" + power_b;
    }

    if(abs(c) <= 9)
    {
        power_c = "00" + power_c;
    }
    else if(abs(c) <= 99)
    {
        power_c = "0" + power_c;
    }

    if(abs(d) <= 9)
    {
        power_d = "00" + power_d;
    }
    else if(abs(d) <= 99)
    {
        power_d = "0" + power_d;
    }

    if(abs(power_f_bldc) <= 9)
    {
        power_b_f = "00" + power_b_f;
    }
    else if(abs(power_f_bldc) <= 99)
    {
        power_b_f = "0" + power_b_f;
    }

    if(abs(power_b_bldc) <= 9)
    {
        power_b_b = "00" + power_b_b;
    }
    else if(abs(power_b_bldc) <= 99)
    {
        power_b_b = "0" + power_b_b;
    }

    String rotate_a = a < 0 ? "1" : "0";
    String rotate_b = b < 0 ? "1" : "0";
    String rotate_c = c < 0 ? "1" : "0";
    String rotate_d = d < 0 ? "1" : "0";

    String send_data = rotate_a + power_a + rotate_b + power_b + rotate_c + power_c + rotate_d + power_d + power_f_bldc + power_b_bldc;

    //Serial.println(send_data);

    Serial2.println(send_data);
    Serial2.flush();
}

void motor_move(int deg, int power)
{
    
    //角度による計算
    float powers[4] = {0, 0, 0, 0};

    deg = 360 - deg - 5;

    powers[0] = sin(radians(deg - 45)) * -power;
    powers[1] = sin(radians(deg + 45)) * -power;
    powers[2] = sin(radians(deg + 135)) * -power;
    powers[3] = sin(radians(deg - 135)) * -power;

    float strongest_power = 0;

    for(int i = 0; i < 4; i++)
    {
        if(abs(powers[i]) > strongest_power)
        {
            strongest_power = abs(powers[i]);
        }
    }   

    if(strongest_power != 0)
    {
        float ratio_of_max_power = power / strongest_power;

        for(int i = 0; i < 4; i++)
        {
            powers[i] = (powers[i] * ratio_of_max_power);
        }
    }

    for(int i = 0; i < 4; i++)
    {
        if(powers[i] <= 50)
        {
            powers[i] -= pid_value;
        }
        else
        {
            if(pid_value < 0)
            {
                if(pid_value < -PID_MOVING_MAX)
                {
                    pid_value = -PID_MOVING_MAX;
                }
            }
            else
            {
                
                if(pid_value > PID_MOVING_MAX)
                {
                    pid_value = PID_MOVING_MAX;
                }
            }

            powers[i] -= pid_value;
        }
    }

    //PIDの値によって値が100より大きくなったとき補正する
    strongest_power = get_max_value_in_array(powers, 4);

    if(strongest_power > 100)
    {
        int diff_val = strongest_power - 100;

        for(int i = 0; i < 4; i++)
        {
            if(powers[i] > 0)
            {
                powers[i] = powers[i] - diff_val;
            }
            else
            {
                powers[i] = powers[i] + diff_val;
            }
        }
    }
    else
    {
        for(int i = 0; i < 4; i++)
        {
            powers[i] = max(min(powers[i], 100), -100);
        }
    }

    motor_direct_drive((int)powers[0], (int)powers[1], (int)powers[2], (int)powers[3]);
}

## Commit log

2024-06-09 なんか色々
    [DRV8332_test.kicad_pcb, DRV8332_test.kicad_sch, OKL-T_6-W12N-C.step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]
2024-10-16 プログラム準備
2024-11-08 初めてのunitV
2024-12-01 カメラのデータ取得・エンジェルラインのデータ取得・UI仮作成中
2024-12-02 プログラム整備、プレゼンシート作成①
2024-12-02 ちょい微調整
2024-12-03 プレゼンシート
2024-12-03 アタッカープログラム構想作成、UI部分仮組み立て、センサー変数の定義
2024-12-03 フォルダ階層の変更
    [DRV8332_test.kicad_pcb, DRV8332_test.kicad_sch, RP2040_test.kicad_pcb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]
2024-12-04 プレゼンシート仮完成
2024-12-06 ボール見えた・ライン見えた・ゴール見えた
2024-12-06 カメラv2
2024-12-22 Tsukuyomiは全国大会用プログラム
2024-12-24 キーパー原型
2024-12-27 とりあえず資料用フォルダ追加
2025-01-08 現状復帰
2025-01-09 ボールと手の区別
2025-01-11 めちゃくちゃよさげ
2025-01-11 ボールと手が同じときは赤を下げる
2025-01-11 KiCadデータ追加
    頑張ってます💪
    [CAM.kicad_pcb, CAM.kicad_sch, Capasitor.kicad_pcb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]
2025-01-29 ファームウェア
2025-01-29 全国用に後で移す
2025-01-30 ファイル整理
2025-01-30 メインプログラム更新
2025-02-10 カメラのプログラム
2025-02-11 プレゼンシート下地
2025-02-14 カメラプログラム
2025-02-15 プレゼンシート更新
2025-02-15 昇圧までは動いた
2025-02-17 カメラ360度
2025-02-17 電圧取れた
2025-02-18 プレゼンシート8割完成！
2025-02-18 微調整②
2025-02-18 あと画像の貼り付けと研究のみ！
2025-02-18 やっぱもうちょっと微調整
2025-02-19 プレゼン更新
2025-02-19 プレゼン修正
2025-02-19 プレゼンシート調整
2025-02-20 NeoPixelテスト
2025-02-20 プレゼンシート9割完成
2025-02-23 KiCad変更
    ごめんさい。溜めました
    [CAM-B_Cu.gbr, CAM-B_Mask.gbr, CAM-B_Paste.gbr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]
2025-02-23 カメラ 前後交代
2025-02-23 PIDまで行った
2025-02-26 ボール追いました
2025-02-28 次回 カメラ：上を外して確認
2025-03-08 カメラとモタドラとTeensyと
2025-03-13 回り込み
2025-03-14 回り込み修正
2025-03-16 回り込みj修正
2025-03-16 シリアル反応なし.
2025-03-17 UIとかラインとか処理追加
2025-03-17 エンジェルラインの角度処理追加
2025-03-20 キーパー実装①
2025-03-21 Revert ";thinking keeper;"
    This reverts commit d8e245b7f309ed206e60094b9ad9a8fcfb07b2bc.
    [camera.py, defender.cpp, main.cpp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]
2025-03-21 Reapply ";thinking keeper;"
    This reverts commit 7145ae71b8c6e74d14a363132d6ce91db272cc4e.
    [camera.py, defender.cpp, main.cpp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]
2025-03-21 ソフトじゃどうにもならんかも.
2025-03-22 キーパー調整②
2025-03-26 悪足掻き
2025-03-27 ディフェンダーで速度制御を使うかどうかを設定できるように
2025-03-31 溜まった変更大放出
    [Capasitor-B_Cu.gbr, Capasitor-B_Mask.gbr, Capasitor-B_Paste.gbr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]
